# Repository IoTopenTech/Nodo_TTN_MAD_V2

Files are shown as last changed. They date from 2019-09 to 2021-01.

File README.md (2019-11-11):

# Nodo_TTN_MAD_V2_2
Documentación, hardware y software del nodo TTN MAD V2.2 desarrollado por la comunidad The Things Network Madrid
En el wiki de este repositorio encontrarás más información sobre cómo montar/adquirir este nodo.
Si lo deseas, también puedes adquirirlo como un kit para montar o ya montado directamente en España (con factura) a través de Molukas:
https://shop.molukas.com/es/inicio/19-56-nodo-ttn-mad-v22.html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

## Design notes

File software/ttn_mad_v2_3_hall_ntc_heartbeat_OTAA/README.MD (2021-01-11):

Programa para el nodo V2.3 en el que la alimentación de la NTC se puede habilitar a demanda mediante el pin digital D6 (es el nodo V2.2 la NTC están constantemente alimentada).
Es el programa que se utiliza en TTNMAD_DOOR.

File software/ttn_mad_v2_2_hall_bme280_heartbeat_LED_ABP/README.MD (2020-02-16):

Ejemplo para la configuración con sensor de efecto Hall, BME280 (temperatura, presión y humedad), envío de heartbeat periódico, y activación/desactivación del LED mediante downlink.
El nodo se activa por ABP.
Envía la tensión de la batería, las lecturas del BME280, y el estado de la puerta cada vez que éste cambia, durmiendo entre cada envío por un máximo de 1 minuto, que es el tiempo predeterminado para el heartbeat.
Con cada heartbeat se envía la misma carga de pago (tensión de la batería, lecturas del BME280 y estado de la puerta).

Si tiene problemas para compilarlo por un error de tipo "segmentation fault", reduzca la versión de las placas Arduino a la versión 1.6.21.

Requiere las siguientes librerías:
* MCCI LoRaWAN LMIC Library by IBM, Matthis Kooijman, Terry Moore, ChaeHee Won, Frank Rose. Versión 2.3.2.
* Low-Power by Rocket Scream Electronics. Versión 1.6.0.
* CayenneLPP by Electronics Cats. Versión 1.0.1
* Adafruit Unified Sensor by Adafruit. Version 1.0.3.
* Adafuir BME280 Library by Adafruit. Version 1.0.8.
   * En el archivo Adafruit_BME280.h hay que cambiar la siguiente línea
   ```
   #define BME280_ADDRESS                (0x76)
   ```
   
Para reducir los requisitos de memoria FLASH de la librería MCCI se debe modificar su archivo MCCI_LoRaWAN_LMIC_library\project_config\lmic_project_config.h del siguiente modo:
```
// project-specific definitions
#define CFG_eu868 1
//#define CFG_us915 1
//#define CFG_au921 1
//#define CFG_as923 1
// #define LMIC_COUNTRY_CODE LMIC_COUNTRY_CODE_JP	/* for as923-JP */
//#define CFG_in866 1
#define CFG_sx1276_radio 1
//#define LMIC_USE_INTERRUPTS
#define DISABLE_PING
#define DISABLE_BEACONS
```

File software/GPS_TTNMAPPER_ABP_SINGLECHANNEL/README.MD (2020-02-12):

En este ejemplo utilizamos un GPS para enviar información a ttnmapper.

Este ejemplo está dirigido a usuarios que sólo disponen de un gateway Single Channel.

El nodo envía la información siempre por el canal 868.1 y en SF7.

Adicionalmente puede conectarse el pin de entrada de la batería al pin A1 mediante una resistencia de 1M para poder medir la tensión, y pulsando el botón (conectado al pin 8) se fuerza el envío de un paquete.

Se ha probado con un GPS VK2828U7G5LF y un GN-701.

Si utiliza el model GN-701 tendrá que retirar una resistencia para habilitar el pin EN (más información en el Wiki).

Cuando se usa el transmisor LoRa se deshabilita el GPS porque el conversor de tensión no es capaz de suministrar corriente suficiente para ambos.

El GPS está conectado al puerto Serial, por lo que el archivo GPSport.h de la librería NeoGPS debe modificarse para que su contenido sea el siguiente:
```
#ifndef GPSport_h
#define GPSport_h

#define gpsPort Serial
#define GPS_PORT_NAME "Serial"
#define DEBUG_PORT Serial

#endif
```
Además, en la librería NeoGPS, debe habilitarse la extracción del valor hdop (horizontal dilution of precision) descomentando la siguiente línea del archivo GPSfix_cfg.h:
```
#define GPS_FIX_HDOP
```
Por último, en la consola de The Thnings Network, debe utilizarse el siguiente decoder en la sección Payload formats:
```
function Decoder(bytes, port) {
    var decoded = {};
    //JavaScript Numbers are Always 64-bit Floating Point
    decoded.latitude = ((((bytes[0]<<(24+32))>>>0) + ((bytes[1]<<(16+32))>>>0) + ((bytes[2]<<(8+32))>>>0) + ((bytes[3]<<(32))>>>0))>>32)/10000000;
    decoded.longitude = ((((bytes[4]<<(24+32))>>>0) + ((bytes[5]<<(16+32))>>>0) + ((bytes[6]<<(8+32))>>>0) + ((bytes[7]<<(32))>>>0))>>32)/10000000;
    decoded.altitude = (((bytes[8]<<24)>>>0) + ((bytes[9]<<16)>>>0) + ((bytes[10]<<8)>>>0) + bytes[11]);
    decoded.hdop=(((bytes[12]<<8)>>>0) + bytes[13])/1000;
    decoded.bateria=(((bytes[14]<<8)>>>0) + bytes[15])*3.3/1023.0;
    return decoded;
}
```

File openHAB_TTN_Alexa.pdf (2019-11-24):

# Domótica openHAB + The Things Network + Alexa

Juan Félix Mateos Barrado
jfmateos@educa.madrid.org
juanfelixmateos@gmail.com

Medialab Prado
Noviembre 2019

## Objetivo

Juan Félix Mateos | 2

# Integrar un nodo de The Things Network en openHAB para poder conocer su temperatura y controlar su LED utilizando comandos de voz a

través de Alexa.

## openHAB

## •Open Home Automation BUS •Creado por Kai Kreuzer (2010) en Java

- Sofware abierto de domótica patrocinado por KNX,

## Z-Wave… - Funciona en Windows, Linux, MacOS, Raspberry

Pi…

## •A partir de openHAB se creó Eclipse SmartHome

(2013) para aplicaciones comerciales.

## Conceptos básicos

Juan Félix Mateos

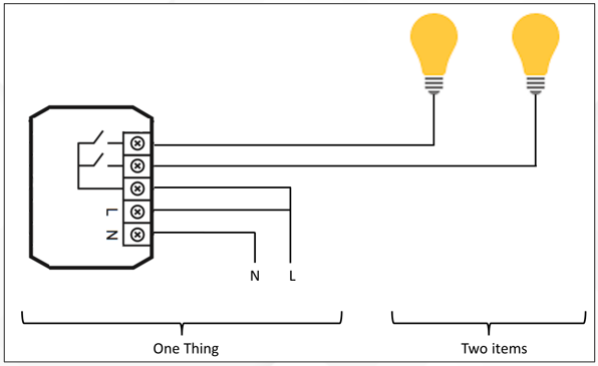
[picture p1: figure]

4

- Things, Items y Channels • Un sensor de temperatura, presión y

humedad es una thing (cosa física), que ofrece 3 canales (temperatura, presión y humedad), con los que el usuario podrá interactuar a través de un item (elemento virtual)
- Bindings • Son las extensiones de openHAB que nos

permiten usar distintos tipos de things (Z

Wave, Zigbee…)
- Rules • Sitemaps • Dashboards

## Orden del día

- Crear una aplicación y un dispositivo en The Things Network
- Instalar Java
- Instalar openHAB
- Instalar el binding JSONPath
- Crear una thing de tipo Generic MQTT Thing con 2 canales vinculados a 2 items:
- Temperatura
- LED
- Crear una regla que active/desactive el LED en el umbral de temperatura de 25º
- Crear un sitemap que muestre la fecha/hora, y los controles de Temperatura y el LED.
- Instalar el binding openHAB Cloud Connector
- Instalar la app de openHAB para el móvil.
- Instalar el binding Rest documentation
- Añadir metadatos a los items para poder controlarlos con Alexa.
- Instalar Alexa en el móvil.
- Configurar el skill de openHAB

## Crear aplicación y dispositivo en TTN

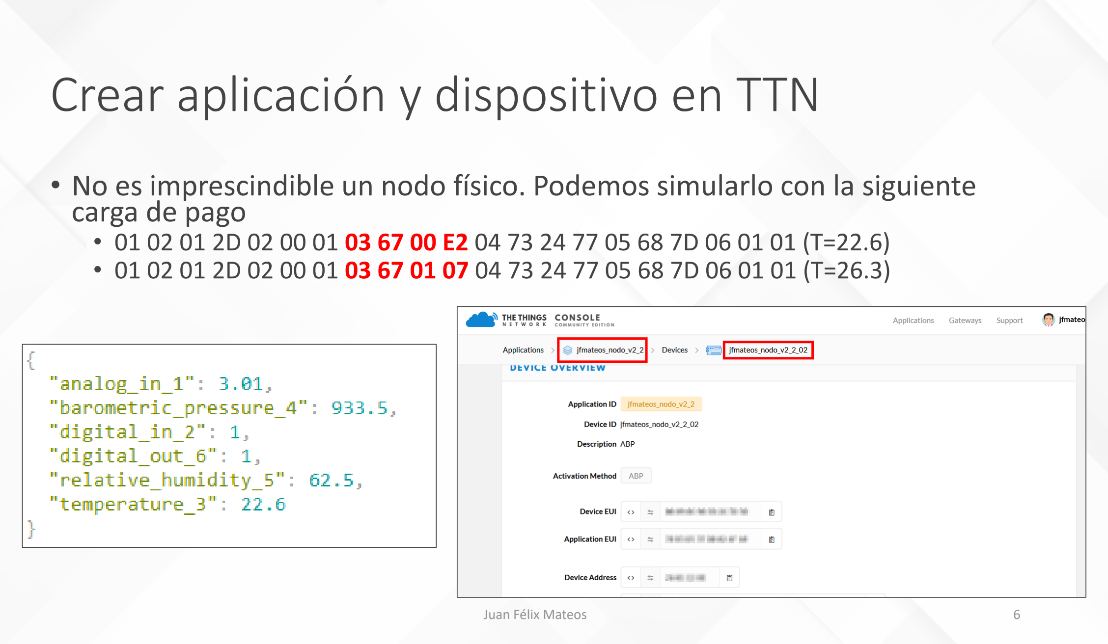
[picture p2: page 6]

- No es imprescindible un nodo físico. Podemos simularlo con la siguiente carga de pago
- 01 02 01 2D 02 00 01 03 67 00 E2 04 73 24 77 05 68 7D 06 01 01 (T=22.6)
- 01 02 01 2D 02 00 01 03 67 01 07 04 73 24 77 05 68 7D 06 01 01 (T=26.3)

## Instalación en Windows 1/2

## •Requiere Java 8 (se recomienda la versión Zulu) •Asegurarse de que está definida la variable de entorno JAVA_HOME

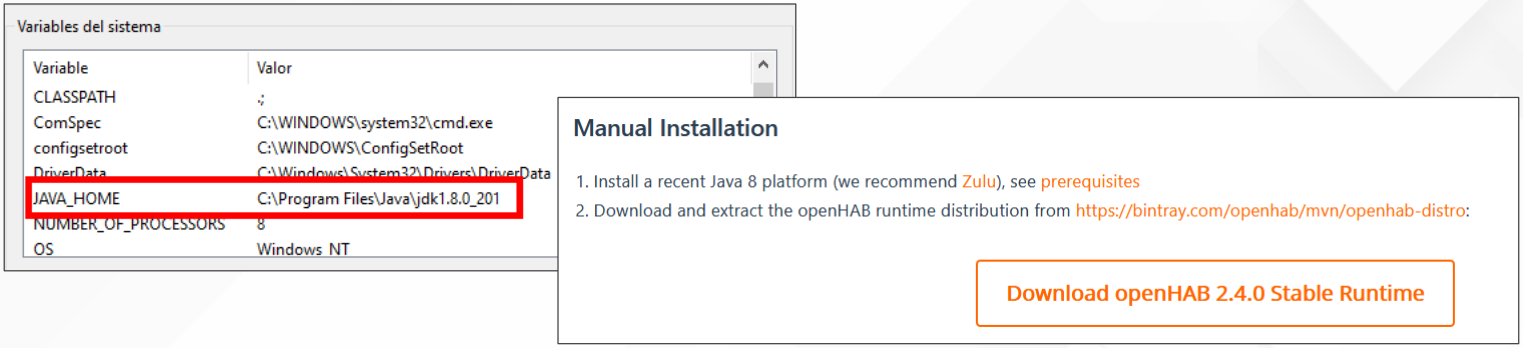
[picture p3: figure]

## Instalación en Windows 2/2

## •Descargar el archivo comprimido de openHAB •Descomprimirlo en una carpeta de nuestro disco duro; por ejemplo C:/openHAB •Ejecutar el archivo start.bat para iniciar openHAB •Acceder con el navegador web a localhost:8080

## Iniciar y detener openHAB

- A través de la consola:
- Windows: C:\openHAB\runtime\bin\karaf.bat
- logout
- Raspberry pi: Putty/SSH
- Usuario: openHABian
- Contraseña: openHABian
- sudo shutdown –h now

## Logs

- Hay 2 logs importantes:
- events.log → Todo los relacionado con las things
- openHAB.log → Todo lo relacionado con los bindings
- Windows
- C:\openHAB\userdata\logs
- Raspberry pi
- http://openHAB:9001/

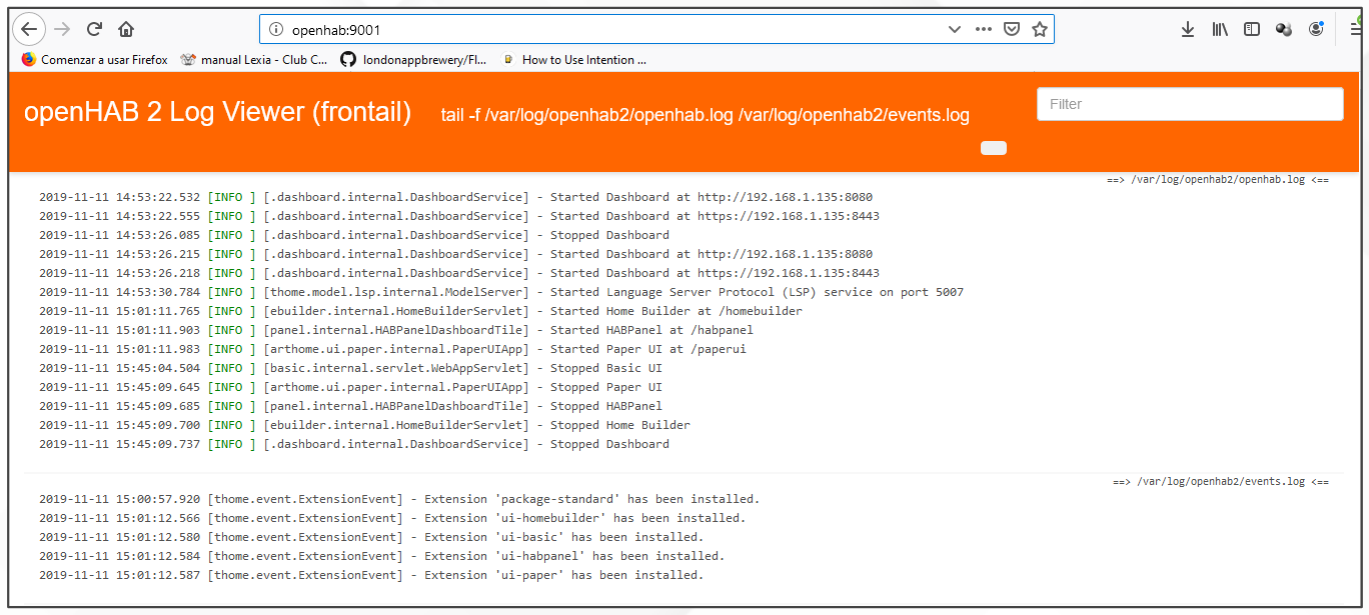
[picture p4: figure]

## Configuración inicial

## Se recomienda utilizar

la opción Standard,

## que instalará las interfaces: • Paper UI • Basic UI •Hab PANEL •Home Builder

## Interfaces (1/2)

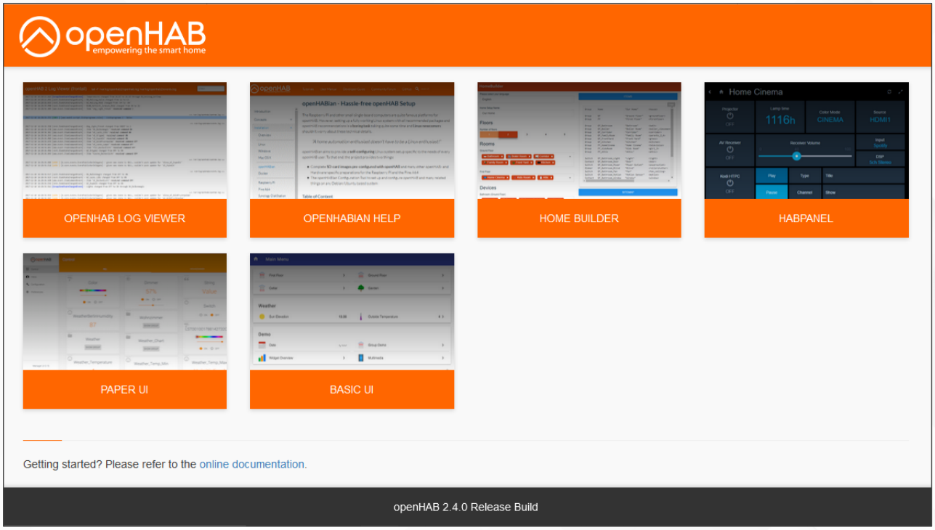
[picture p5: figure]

## Interfaces (2/2)

- Paper UI: Ideal para configurar openHAB.
- Basic UI: Ideal para mostrar los Site maps
- HABPanel: Sirve para diseñar Dashboards.
- Home Builder: Sirve para generar una configuración inicial compuesta por:
- Items
- Sitemaps
- Dashboards

## MQTT

- Broker
- Suscripción/Publicación
- Topic
- Vamos a vincular openHAB con el bróker MQTT de The Things Network

## MQTT

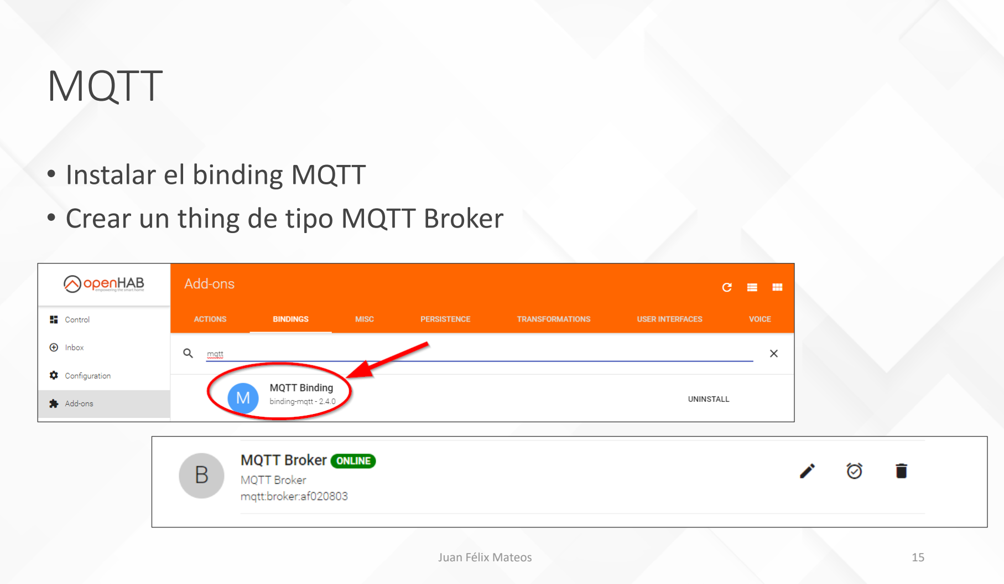
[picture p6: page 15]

- Instalar el binding MQTT
- Crear un thing de tipo MQTT Broker

## MQTT: Configurar la thing MQTT Broker

- Broker: eu.thethings.network
- Username: Nombre de la aplicación en TTN
- Password: Default key de TTN

## MQTT: Crear una Generic MQTT Thing

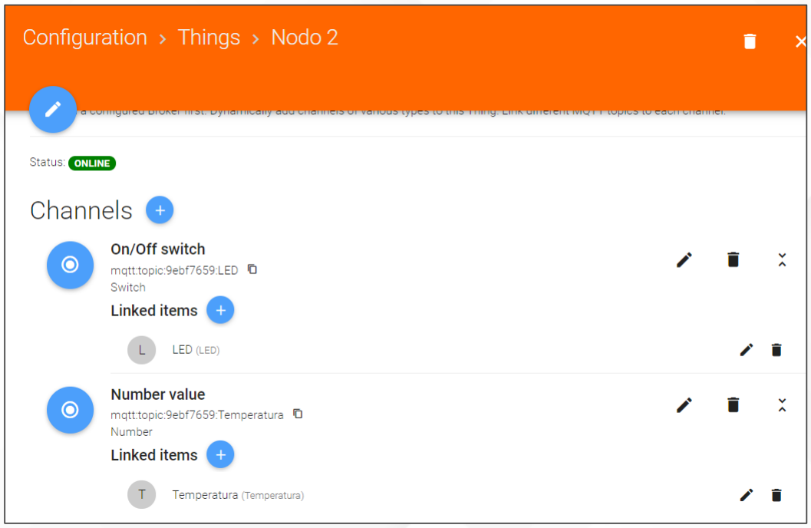
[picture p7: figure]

- El thing Broker es el soporte general
para poder usar MQTT en openHAB,
pero adicionalmente tenemos que crear un thing de tipo Generic MQTT Thing para cada elemento que queramos controlar.
- Crear una thing de tipo Generic MQTT Thing con 2 canales vinculados a los siguientes items:
- Number value: Temperatura
- On/Off Switch: LED

## MQTT: Canal para recibir uplink

- Configurar el canal de tipo Number Value del siguiente modo

El 20 de noviembre de 2019 han desactivado la publicación de los decoded fields en topics MQTT independientes;
consecuentemente este sistema no funciona (ver diapositiva siguiente)

## MQTT: Canal para recibir uplink (alternativa)

- En lugar de suscribirnos al topic concreto de la temperatura, nos suscribiremos al topic completo, y extraeremos de él la temperatura mediante una transformación.
- Instalar el binding JSONPath Transformation

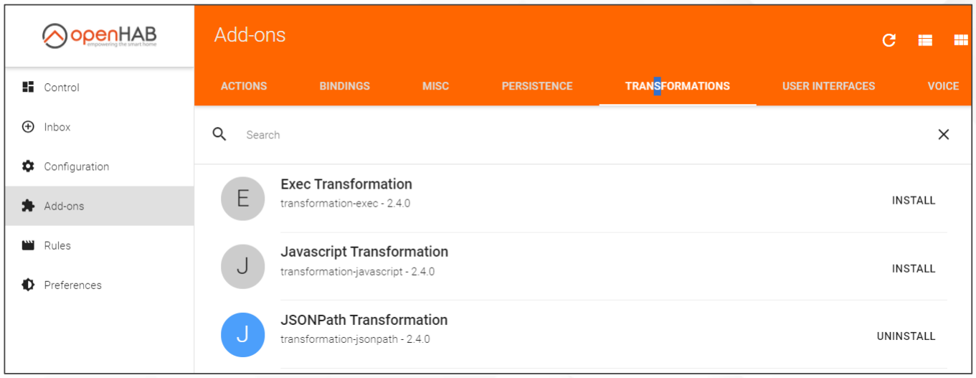
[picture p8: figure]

## MQTT: Canal para recibir uplink (alternativa)

- Configurar el canal de temperatura del siguiente modo

## MQTT: Canal para enviar downlink

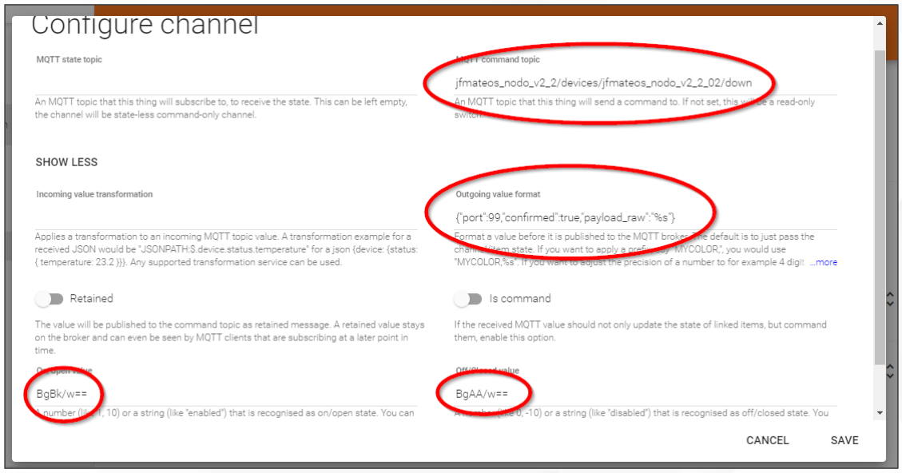
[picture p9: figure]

- Configurar el canal de tipo
On/Off Switch del siguiente
modo
- BgBk/w== y BgAA/w== son la codificación en BASE64 de 06 00 64 FF y 06 00 00 FF, que son la carga de pago que
espera recibir el nodo para encender y apagar el led,
respectivamente
- jfmateos_nodo_v2_2/devices/jf mateos_nodo_v2_2_02/down
- {"port":99,"confirmed":true,"pa yload_raw":"%s"}

## MQTT: Canal para enviar downlink

- En la versión 2.4 de openHAB hay un bug que impide que se inicie automáticamente el cliente MQTT
- Para resolverlo hay que cerrar openHAB (logout) y volver a iniciarlo.

## Reglas

## Nos permiten reaccionar ante:

- el cambio de estado de los ítems
- Things y canales (de forma más limitada)
- instantes (fecha y/u hora) concretos
- eventos del sistema (que se inicie o se apague)

## con acciones como:

- enviar un comando a un item
- utilizar un servicio (enviar un mail, notificación…)

## - La sintaxis está basada en Xbase

## Reglas: Encender/apagar el LED en el umbral de 25º

Crear en la carpeta C:\openHAB\conf\rules un archivo llamado default.rules con el siguiente contenido:

rule "LED"
when
Item Temperatura changed
then
if (Temperatura.state >= 25 && previousState<25) { LED.sendCommand(ON)
} else {
if(Temperatura.state < 25 && previousState>=25) { LED.sendCommand(OFF)
}
}
end

## Sitemaps

Son representaciones destinadas al usuario para conocer el estado del sistema o interactuar con él.
Están compuestos por elementos de distintos tipos:
- Pulsadores
- Deslizadores
- Selectores de color
- …
Los sitemaps se crean en archivos de texto con la extensión sitemap dentro de la carpeta:
- C:\openHAB\conf\sitemaps
En Paper UI disponemos de la sección Control, pero sólo sirve para Things (los sitemaps y dashboards funcionan principalmente a nivel de items).

## Sitemaps

Cada sitemap debe empezar con un elemento de tipo sitemap sitemap <nombre> label="<título de la pantalla inicial>" {
[resto de elementos]
}
El <nombre> debe coincidir con el nombre del archivo; por ejemplo, si el sitemap se llama habitacion_invitados, el archivo deberá llamarse habitacion_invitados.sitemap.

## Sitemaps

Cada elemento tendrá la siguiente sintaxis: tipo item=nombre label="Rotulo"
Donde tipo puede ser:
- Switch
- Slider
- Text
- Image
- Frame (para agrupar)
- …
Y nombre es el nombre del item.

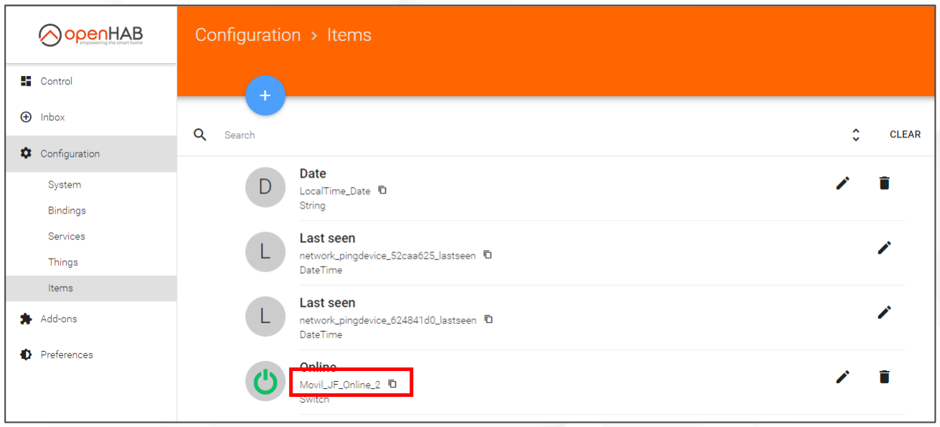
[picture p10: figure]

## Sitemaps

Si lo deseamos podemos
cambiar el icono del item en el sitemap eligiendo cualquiera de los disponibles en:
https://www.openHAB.org/docs/configuration/iconsets/classic/ Y escribiendo su nombre en Category

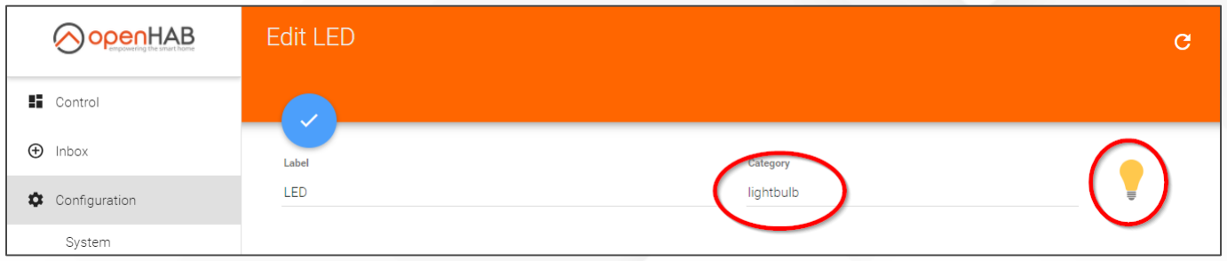
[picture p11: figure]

## Sitemaps: things

Crear el archivo C:\openHAB\conf\sitemaps\ttn.sitemap con el siguiente contenido:

sitemap ttn label="<The Things Network Madrid>" {
Switch item=LED label="LED"
Text item=Temperatura label="Salon [%.1f °C]" icon="temperature" }

## Sitemaps: Basic UI

Configura Basic UI para que utilice como sitemap por defecto el que hemos creado anteriormente (habitación_invitados).

## Sitemaps: Basic UI

Acceder a Basic UI a través de http://localhost:8080

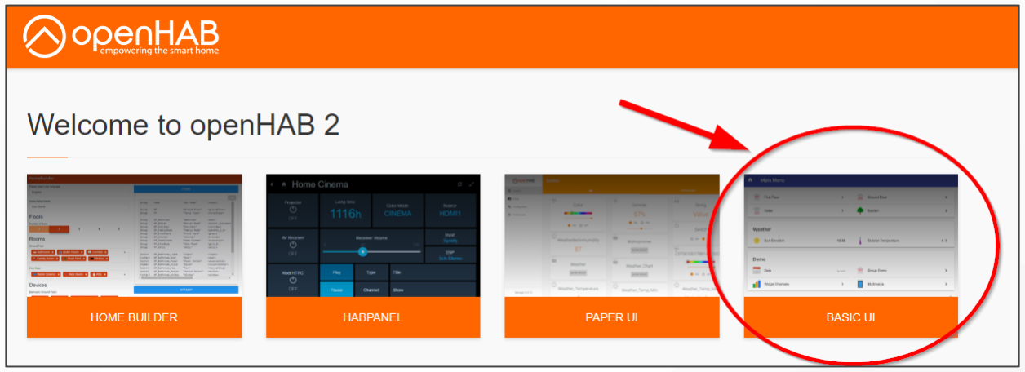
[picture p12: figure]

## Sitemaps

Además de crear ítems a través de Paper UI, también podemos hacerlo a través de documentos de texto con la extensión .items en la carpeta C:\openHAB\conf\items
Por ejemplo, vamos a incluir en el sitemap un item que muestre la fecha:
1. Importar el binding NTP.
2. Crear la thing correspondiente a través de Inbox.
3. Configurar el item a través de un archivo .items.

## Sitemaps

Importar el binding NTP.

## Sitemaps

Crear la thing correspondiente a través de Inbox.

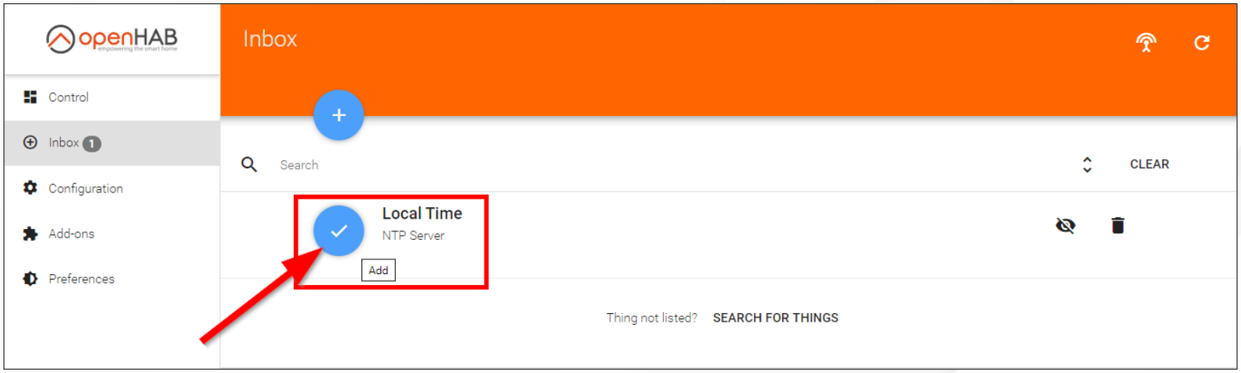
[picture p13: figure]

## Sitemaps

Cada elemento (item)
debe crearse con la
siguiente sintaxis
tipoElemento
nombreElemento
"Descripción" <icono> {
canal }
Donde tipoElemento
puede ser cualquiera de la tabla.

## Sitemaps

<icono> puede ser cualquiera de esta lista https://www.openHAB.org/docs/configuration/iconsets/classic/

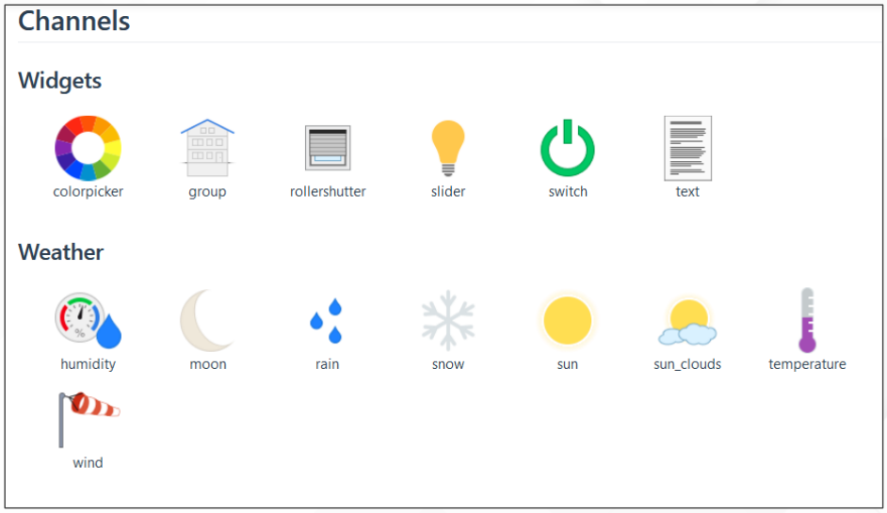
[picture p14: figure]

## Sitemaps

Y canal es el nombre del canal que vincula la thing con el item, y que podemos obtener en la configuración de la thing

## Sitemaps

Crear el archivo C:\openHAB\conf\items\miselementos.items con el siguiente contenido:

String Fecha_NTP "Fecha" <calendar> { channel="ntp:ntp:local:string" }

Y modificar el archivo ttn.sitemap:

sitemap ttn label="<The Things Network Madrid>" {
Text item=Fecha_NTP label="Fecha"
Switch item=LED label="LED"
Text item=Temperatura label="Salon [%.1f °C]" icon="temperature" }

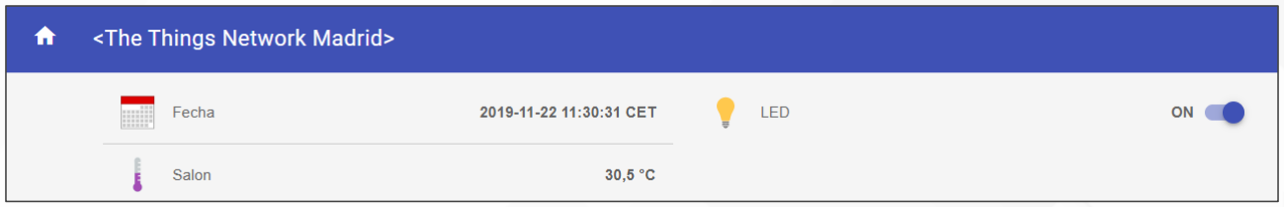
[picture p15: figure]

## App móvil

Instalar el Add-on openHAB Cloud Connector

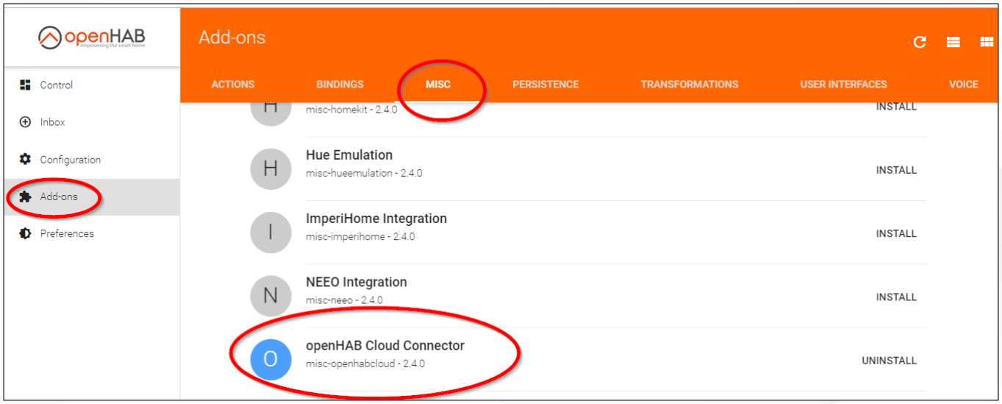
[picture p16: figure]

## App móvil

Configurar openHAB Cloud Connector para que utilice el servidor https://myopenhab.org

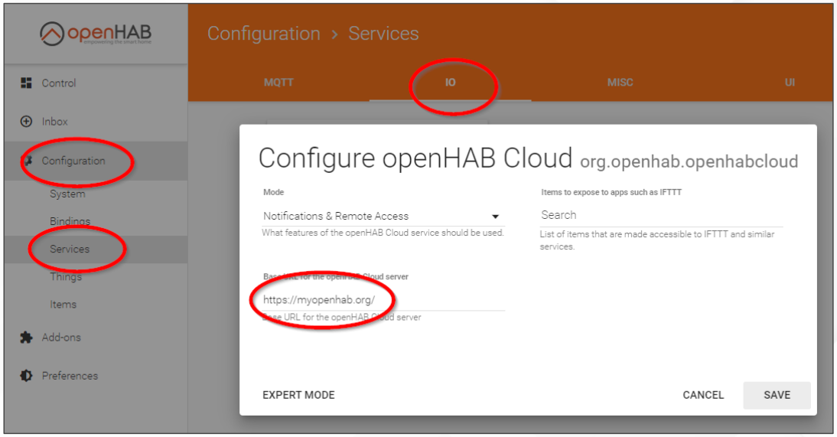
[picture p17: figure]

## App móvil

Crear una cuenta en
https://myopenhab.org
- UUID:
C:\openHAB\userdata\uuid
- Secret:
C:\openHAB\userdata\ope
nhabcloud\secret

## App móvil

Instalar la aplicación en el móvil

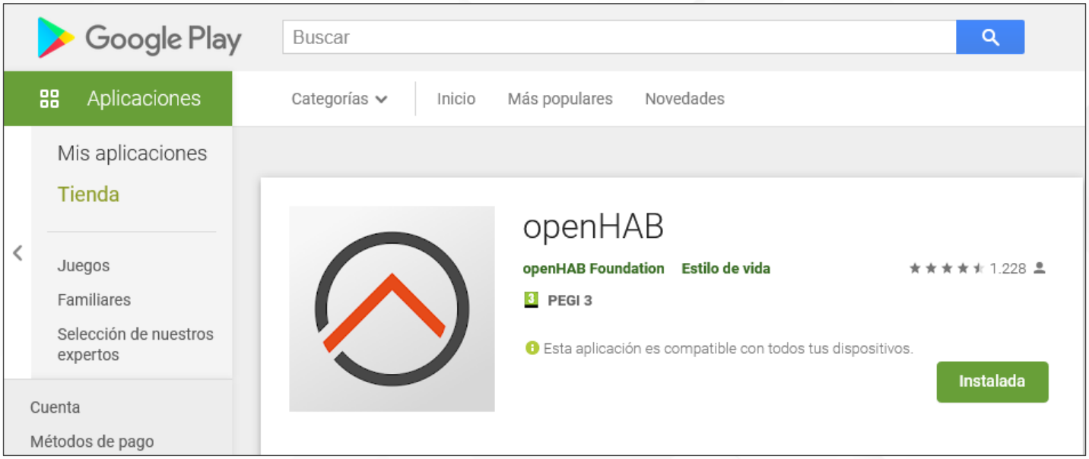
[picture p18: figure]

## App móvil

Configurar la app para que se conecte a myopenhab.org

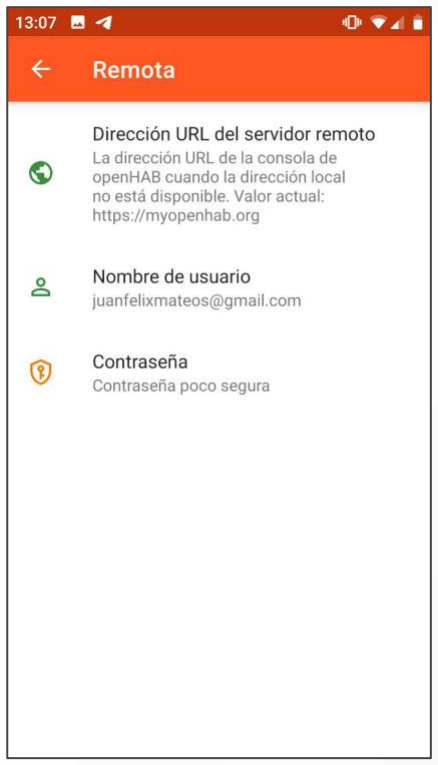
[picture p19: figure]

## Alexa

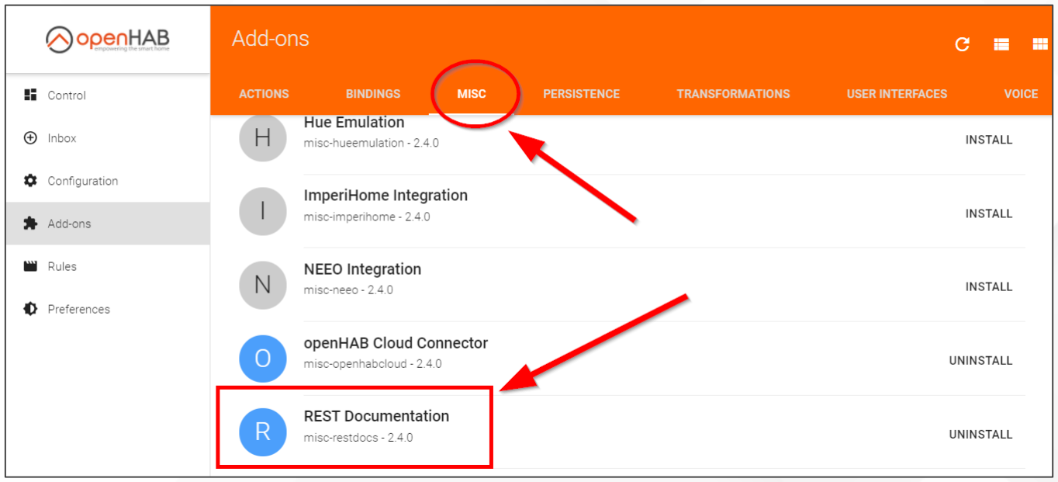
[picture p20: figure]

Para que Alexa pueda identificar a nuestro nodo necesitamos
aportar a los items
metainformación que indique qué posibilidades ofrecen.
Para aportar esta
metainformación vamos a recurrir a la Rest API de openHab que, si instalamos el binding openHAB Rest Documentation, está
disponible a través de Swagger en: • http://localhost:8080/doc/index

.html (http://localhost:8080/doc/index.html)

## Alexa

El listado de metadatos está disponible en:
- https://www.openhab.org/docs/ecosystem/alexa/#supported-item-metadata
- Por ejemplo:
- Interruptor: PowerController.powerState
- Sensor: TemperatureSensor.temperature

## Alexa

Metadatos de LED

## Alexa

Podemos comprobar que el metadato se ha añadido correctamente revisando el archivo:
- C:\openHAB\userdata\jsondb\org.eclipse.smarthome.core.items.Me tadata.json

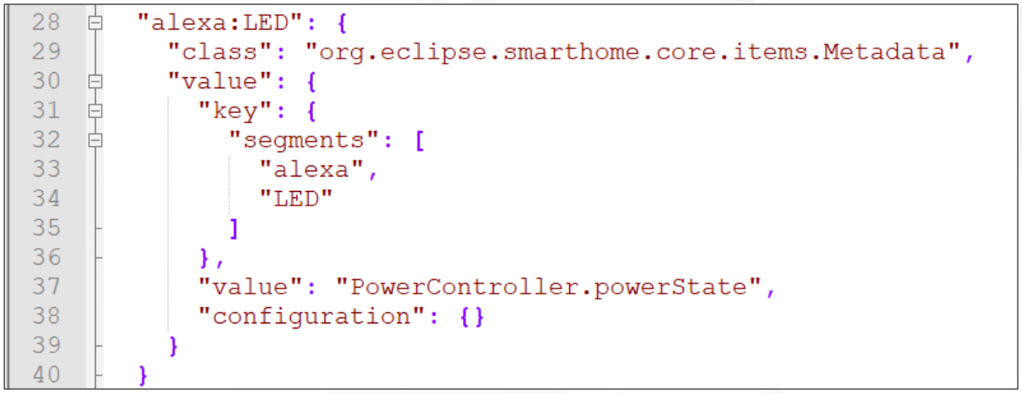
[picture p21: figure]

## Alexa

Metadatos de Temperatura

## Alexa

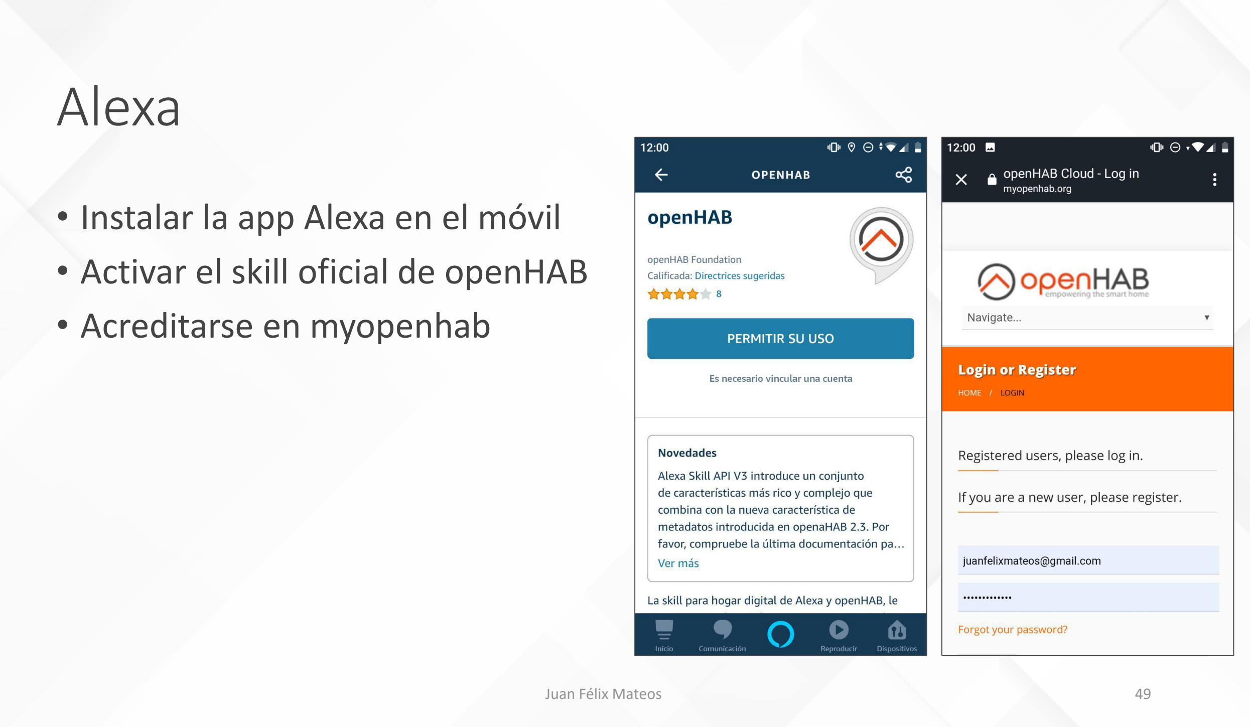
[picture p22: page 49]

- Instalar la app Alexa en el móvil
- Activar el skill oficial de openHAB
- Acreditarse en myopenhab

## Alexa

- Aceptar la autorización OAuth2
- Permitir que Alexa detecte nuestros 2 dispositivos

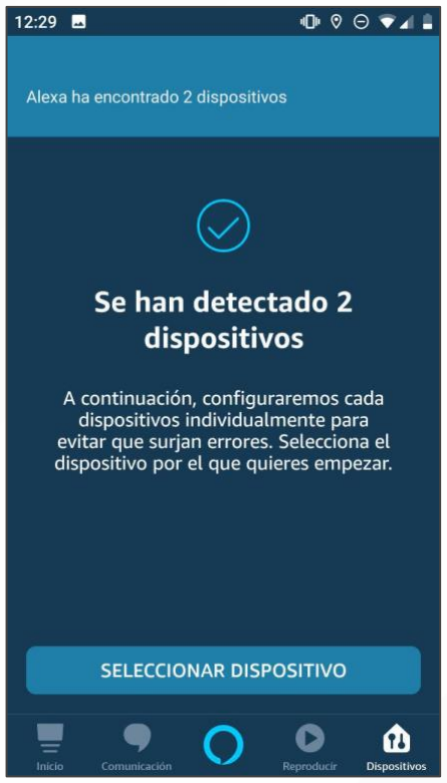
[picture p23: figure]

## Alexa

Interactuar con los siguientes comandos de voz:
- ¿Cuál es la temperatura de Temperatura?
- Activa LED
- Desactiva LED
- ¿Cuál es el estado de LED?
- Todavía no está disponible ¿o sí?
- https://github.com/openhab/openhab-alexa/issues/239

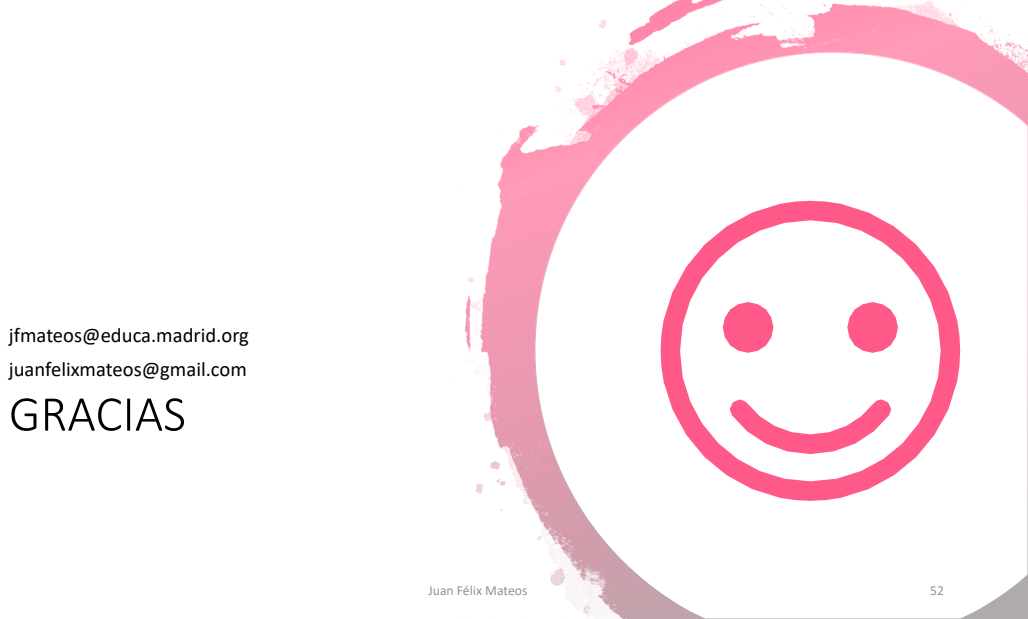
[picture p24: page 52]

jfmateos@educa.madrid.org
juanfelixmateos@gmail.com
GRACIAS

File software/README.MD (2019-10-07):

En esta carpeta se recogen varios ejemplos de funcionamiento del nodo TTN MAD V2.2.

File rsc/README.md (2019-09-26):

Esta carpeta contiene las imágenes y recursos que se utilizan en el wiki.

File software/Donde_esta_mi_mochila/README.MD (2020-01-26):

Este ejemplo puede funcionar en dos modos diferentes:
* Modo Heartbeat: Envía cada 15' la tensión de la batería 
* Modo Tracking: Envía cada 5' la tensión de la batería, la posición GPS y la MAC de los 2 puntos de acceso con mejor RSSI. La adquisición de las direcciones MAC permitiría obtener una geolocalización aproximada, incluso en interiores o zonas sin cobertura GPS, mediante el uso de servicios como http://api.mylnikov.org/geolocation/wifi?v=1.1&data=open&bssid={wifi-bssid}

Identificación de elementos

Nodo completo

La carga de pago usa el estándar Cayenne LPP. Como no existe un modelo de datos para direcciones MAC en LPP, se codifican los 6 bytes de cada MAC en 3 paquetes de 2 bytes, que se envían cada uno como datos de luminosidad.

Integración con MyDevices

Inicialmente arranca en el modo Heartbeat, y se puede intercambiar entre uno y otro modo usando cualquiera de estos dos métodos:
* Usando el botón: Con una triple pulsación del botón en menos de 2'' pero con más de 500ms de separación entre pulsación y pulsación. El botón está conectado a los bornes SW y GND del terminal de tornillos verde. El botón elegido es el mismo que para la extensión WiFi (SMD 3x6x2,5).
* Mediante downlink: Se recomienda usar downlink con ACK para asegurarse de que es efectivamente recibido por el nodo. Un downlink con la carga de pago 02 00 64 FF activará el modo Tracking, y usando la carga de pago 02 00 00 FF se activará el modo Heartbeat.

En modo Tracking el LED del nodo parpadea al menos cada 8 segundos en la fase dormida, y cada segundo aproximadamente si está en las fases de adquisición de GPS o WiFi.

Requiere las extensiones WIFI, BOOSTER y GPS, y adicionalmente un botón SMD 3x6x2,5 como el de la extensión WIFI..

Puede configurarse a través del portal cautivo WiFi para unirse a la red por OTAA o ABP.
Sin embargo, en modo ABP no almacena de forma no volátil los contadores, por lo que ante un fallo de alimentación se reiniciarían; en caso de configurarlo en modo ABP se recomienda deshabilitar la comprobación de contador en la consola de The Things Network.

Requiere las siguientes librerías:
* MCCI LoRaWAN LMIC Library by IBM, Matthis Kooijman, Terry Moore, ChaeHee Won, Frank Rose. Versión 2.3.2.
* Low-Power by Rocket Scream Electronics. Versión 1.6.0.
* NeoGPS by SlashDevin 4.2.9

Para reducir los requisitos de memoria FLASH de la librería MCCI se debe modificar su archivo MCCI_LoRaWAN_LMIC_library\project_config\lmic_project_config.h del siguiente modo:
```
// project-specific definitions
#define CFG_eu868 1
//#define CFG_us915 1
//#define CFG_au921 1
//#define CFG_as923 1
// #define LMIC_COUNTRY_CODE LMIC_COUNTRY_CODE_JP	/* for as923-JP */
//#define CFG_in866 1
#define CFG_sx1276_radio 1
//#define LMIC_USE_INTERRUPTS
#define DISABLE_PING
#define DISABLE_BEACONS
```
Se ha probado con un GPS G28U7FTTL.
Cuando se usa el transmisor LoRa se deshabilita el GPS porque el conversor de tensión no es capaz de suministrar corriente suficiente para ambos. Tampoco se utilizan simultáneamente el GPS y el ESP03 por el mismo motivo.
El GPS está conectado al puerto Serial, por lo que el archivo GPSport.h de la librería NeoGPS debe modificarse para que su contenido sea el siguiente:
```
#ifndef GPSport_h
#define GPSport_h

#define gpsPort Serial
#define GPS_PORT_NAME "Serial"
#define DEBUG_PORT Serial

#endif
```
La tensión de la batería se mide a través del pin A1 intercalando una resistencia de 1M entre el borne 3v3 del terminal de tornillos y el orificio A1 de la sub-placa de expansión.

Se ha incluido también una resistencia de 1M en configuración puldown entre el pin PIR de la sub-placa de expansión y el ping GND de la sub-placa de expansión para que el GPS arranque inicialmente deshabilitado.

Para entrar en el modo de configuración por WiFi hay que mantener pulsado el botón del pcb (no el de cambio entre los modos Heartbeat y Tracking) durante el arranque del nodo.

Cuando el ESP03 arranca empieza a mandar por el puerto serie "IoT" cada segundo, y espera recibir un "1" para entrar en el modo de configuración por WiFi, o un "2" para entrar en el modo de adquisición de las direcciones MAC de los 2 puntos de acceso con mejor RSSI.

El modelo 3D de la caja está diseñado con TinkerCAD y disponible en  https://www.tinkercad.com/things/hX5CWUOLzT4 

El asa se sujeta mediante 2 tuercas M2 y dos tornillos M2x5mm.
El soporte para el botón conviene fijarlo con pegamento termofusible.

Piezas 3D

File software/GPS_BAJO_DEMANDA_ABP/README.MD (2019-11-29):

En este ejemplo utilizamos un GPS.
El nodo envía un heartbeat cada 24 segundos con la tensión de la batería.
Cada 12 ciclos de 24 segundos, incluye en el heartbeat la posición GPS (si consigue hacer un fix antes de 5 minutos).
El usuario puede enviar un downlink con la carga de pago 02 00 64 FF para activar el modo de seguimiento; en este modo el GPS se habilita y se envía un paquete cada minuto.
Enviando un downlink con la carga de pago 02 00 00 FF se desactiva el modo de seguimiento.
Se ha probado con un GPS VK2828U7G5LF.
Cuando se usa el transmisor LoRa se deshabilita el GPS porque el conversor de tensión no es capaz de suministrar corriente suficiente para ambos.
El GPS está conectado al puerto Serial, por lo que el archivo GPSport.h de la librería NeoGPS debe modificarse para que su contenido sea el siguiente:
```
#ifndef GPSport_h
#define GPSport_h

#define gpsPort Serial
#define GPS_PORT_NAME "Serial"
#define DEBUG_PORT Serial

#endif
```


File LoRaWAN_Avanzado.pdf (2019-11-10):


CONSTRUYENDO UNA RED GLOBAL DE INTERNET

DE LAS COSAS ENTRE TOD@S

Facendo IoT con LoRaWAN. Introdución

juanfelixmateos@gmail.com

Integraciones

## - Data Storage

## - Cayenne

## - IFTTT

## - Node-RED

Juan Félix Mateos

Data Storage



Data Storage

Data Storage


Cayenne MyDevices


Cayenne MyDevices


Cayenne MyDevices


Cayenne MyDevices


Cayenne MyDevices


IFT T T = If This Then That


IFT T T = If This Then That


IFT T T = If This Then That

IFT T T = If This Then That


IFT T T = If This Then That

IFT T T = If This Then That

IFT T T = If This Then That


IFT T T = If This Then That


IFT T T = If This Then That


IFT T T = If This Then That

Node-RED

- Desarrollado por IBM en 2013 → Open Source
- Objetivo: Facilitar la construcción de sistemas IoT
- Programación visual basada en nodos y flujos
- Los nodos "consumen" y "produce" mensajes
- Un mensaje es un objeto JavaScript, que contiene al menos la propiedad payload
- msg={payload:"juanfe"};
- Adicionalmente, por defecto, todos los mensajes poseen las propiedades topic y _msgid

Node-RED: Tipos de nodos

- Entrada
- Salida
- Función
- Otros

Node-RED: Nodos y deployment


- Deployment/Despliegue = Poner en funcionamiento


Node-RED: Ejemplo básico

- En función del valor recibido, redirigimos la ejecución hacia un nodo u otro


Node-RED: Fred


Node-RED: Fred

Node-RED: Fred


Node-RED: Fred


Node-RED: Fred

HT TP Integration

- Podemos utilizar RequestBin para analizar el formato que utiliza TTN


YOU ARE THE NETWORK

LET ’S BUILD THIS THING TOGETHER!

Juan Félix Mateos

juanfelixmateos@gmail.com

w w w. t h e t hi n g s n e t w o r k . o r g

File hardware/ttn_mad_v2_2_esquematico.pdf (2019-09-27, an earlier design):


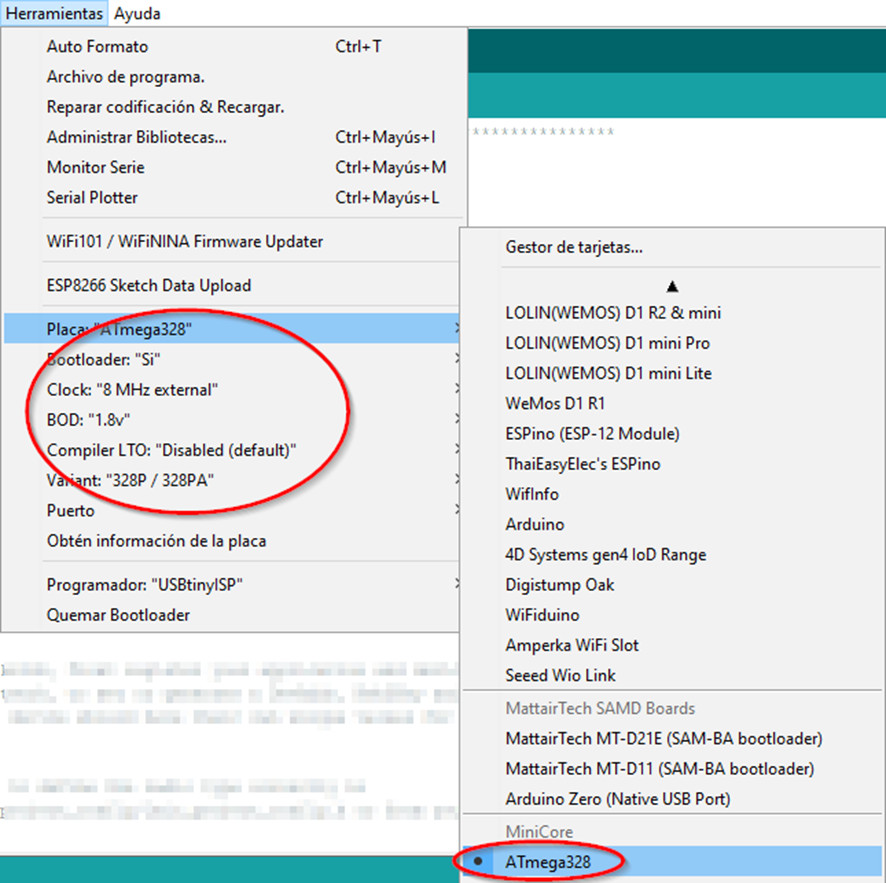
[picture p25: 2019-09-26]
rsc/TTN_MAD_V2_2_minicore.jpg

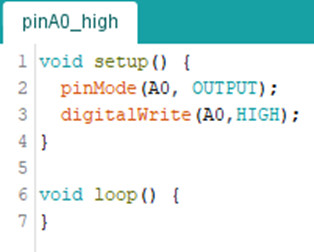
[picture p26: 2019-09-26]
rsc/TTN_MAD_V2_2_enableesp03.jpg

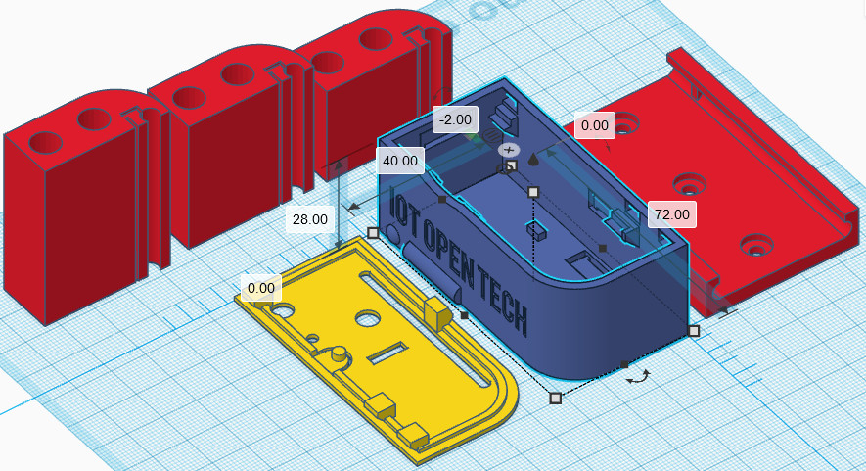
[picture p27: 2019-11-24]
rsc/TTN_MAD_V2_2_caja3d.jpg

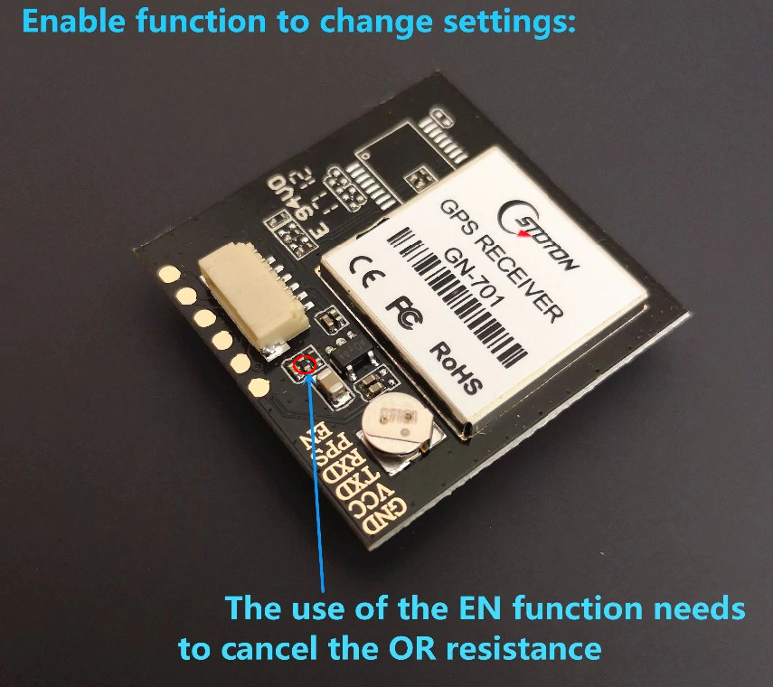
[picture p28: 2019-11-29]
rsc/gn-701.jpg

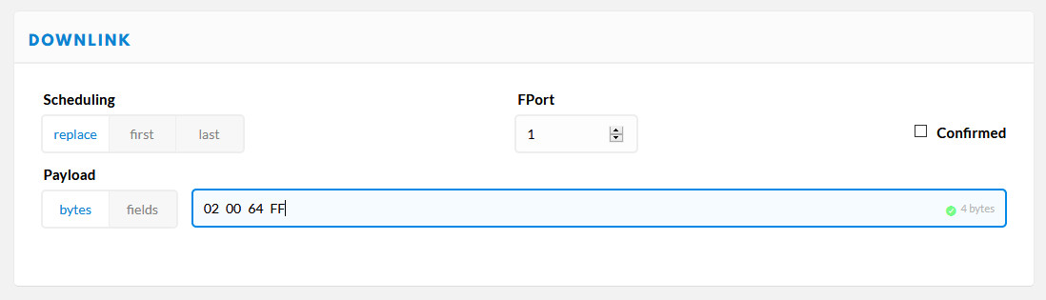
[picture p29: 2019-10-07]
rsc/TTN_MAD_V2_2_downlink.jpg

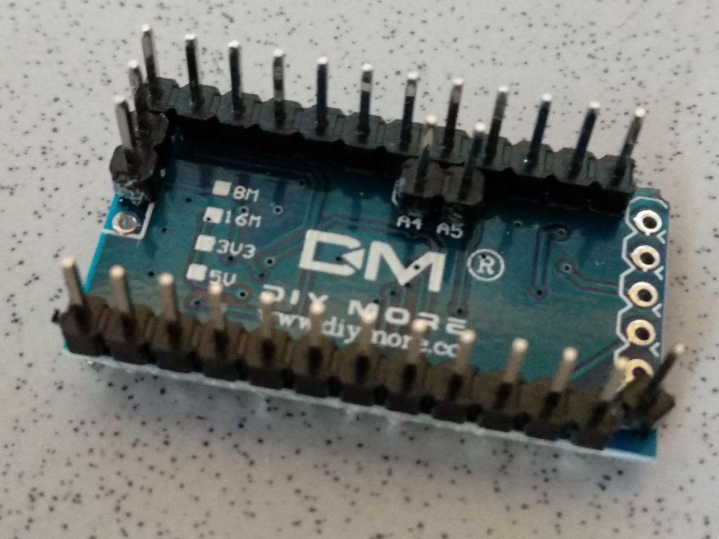
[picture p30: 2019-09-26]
rsc/ttn_mad_v2_arduino.jpg

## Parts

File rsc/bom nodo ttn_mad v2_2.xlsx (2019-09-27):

BOM nodo TTN MAD V2.2
Configuración | Componentes | Ejemplo de enlace de compra | Observaciones
Básica
 | 1x Arduino Pro Mini 8MHz 3.3V | https://es.aliexpress.com/item/32672156652.html
 | 1x RFM95W versión 868 MHz | https://es.aliexpress.com/item/32811523237.html
 | 1x Antena helicoidal | https://es.aliexpress.com/item/1989211654.html
 | 1x Header 4 entradas con tornillo | https://es.aliexpress.com/item/32620313513.html
 | 1x Portabaterías doble AAA | https://es.aliexpress.com/item/32970184341.html
 | 1x Botón On/Off | https://es.aliexpress.com/item/32696389272.html
 | 2x Batería alcalina AAA
Extensión Hall
 | 1x Sensor efecto hall (recomendado) o reed switch abierto en presencia del imán | https://www.mouser.es/ProductDetail/595-DRV5032FBDBZR | Recomendado
 |  | https://es.aliexpress.com/item/32762713233.html | Alternativa 1. Incluye el imán
 |  | https://es.aliexpress.com/item/32791579301.html | Alternativa 2.
 | 1x Imán de neodimio cilíndrico 5x10mm (sólo si no lo incluye el sensor anterior) | https://es.aliexpress.com/item/4000087186269.html
Extensión auxiliar I2C
 | 2x Resistencia 4.7K en formato 0603 | https://es.aliexpress.com/item/32506721498.html
Extensión auxiliar booster
Esta extensión es imprescindible para los componentes que requieren alimentación a 3.3V, como el ESP03. Además permite aprovechar mejor las baterías. | 1x TPS613221ADBVR | https://www.mouser.es/ProductDetail/595-TPS613221ADBVR
 | 1x Bobina 2.2uH | https://www.mouser.es/ProductDetail/652-SRN2512-2R2M
 | 2x Condensador 10uF en formato 0603 | https://es.aliexpress.com/item/32908565720.html
 | 2x Condensador 22uF en formato 0603 | https://es.aliexpress.com/item/32945148180.html
Extensión auxiliar puerto de ampliación
El puerto de ampliación puede utilizarse para conectar otros sensores y actuadores (ej. GPS), o bien para colocar un sensor a cierta distancia del nodo principal (ej. dentro de un congelador). | 1x Cable FPC 10p pines forward direction 0.5mm de pitch de la longitud deseada | https://es.aliexpress.com/item/32957238371.html
 | 2x Conector FPC 10 pines 0.5mm de pitch | https://es.aliexpress.com/item/32794865292.html
Extensión WiFI (recomendada). Requiere extensión auxiliar booster
Permite configurar el nodo a través de una página web sin tener que usar un programador conectado al ordenador. | 1x Esp03 | https://es.aliexpress.com/item/32834908262.html
 | 3x Resistencia 10k en formato 0603 | https://es.aliexpress.com/item/32887413843.html
 | 1x MIC94092YC6TR | https://www.mouser.es/ProductDetail/998-MIC94092YC6TR
 | 1x Condensador 100n en formato 0603 | https://es.aliexpress.com/item/32947901307.html
 | 1x Botón momentáneo normalmente abierto | https://es.aliexpress.com/item/32809371269.html
Extensión LED
 | 1x LED rojo en formato 1206 | https://es.aliexpress.com/item/32985163457.html
 | 1x Resistencia 150ohm en formato 0603 | https://es.aliexpress.com/item/4000094254339.html
Extensión buzzer
 | 1x Buzzer | https://es.aliexpress.com/item/32458823676.html
 | 1x BC817 | https://es.aliexpress.com/item/32947715617.html
 | 1x Resistencia 150ohm en formato 0603 | https://es.aliexpress.com/item/4000094254339.html
Extensión memoria ferromagnética. Requiere extensión auxiliar booster y extensión auxiliar I2C
Los paquete LoRaWAN incluyen un contador creciente por motivos de seguridad. Si el nodo se configura para acceder a la red por ABP y sufre una pérdida de alimentación, al reiniciarse deberá seguir con la secuencia de contador, por lo que necesitará tenerla almacenada en una memoria no volátil (que es lo que aporta esta extensión). Si configuramos el nodo para acceder a la red por OTAA, o si anulamos la medida de seguridad del contador no se requiere esta extensión. | 1x FM24CL16B | https://www.mouser.es/ProductDetail/877-FM24CL16B-GTR
 | 1x Condensador 100n en formato 0603 | https://es.aliexpress.com/item/32947901307.html
Extensión BME280. Requiere extensión auxiliar I2C
 | 1x BME280 | https://www.mouser.es/ProductDetail/Bosch-Sensortec/BME280
 | 1x Condensador 100n en formato 0603 | https://es.aliexpress.com/item/32947901307.html
Extensión BMA253. Requiere extensión auxiliar I2C
 | 1x BMA253 | https://www.mouser.es/ProductDetail/Bosch-Sensortec/BMA253
 | 1x Condensador 100n en formato 0603 | https://es.aliexpress.com/item/32947901307.html
Extensión PIR. Requiere extensión auxiliar booster
 | 1x MH-SR602 | https://es.aliexpress.com/item/32899134070.html
 | 1x Header hembra 3 pines | https://es.aliexpress.com/item/32849618420.html
Extensión GPS. Requiere extensión auxiliar booster y extensión auxiliar puerto de ampliación
 | 1x Módulo GPS | https://es.aliexpress.com/item/32947981053.html
Extensión LDR
 | 1x LDR tipo GL5506 | https://es.aliexpress.com/item/32630707917.html
 | 1x Resistencia 4.7k en formato 0603 | https://es.aliexpress.com/item/32506721498.html
Extensión NTC
 | 1x NTC MF52 10K 3950 | https://es.aliexpress.com/item/2044621392.html
 | 1x Resistencia 8.2k en formato 0603 | https://es.aliexpress.com/item/4000134157979.html

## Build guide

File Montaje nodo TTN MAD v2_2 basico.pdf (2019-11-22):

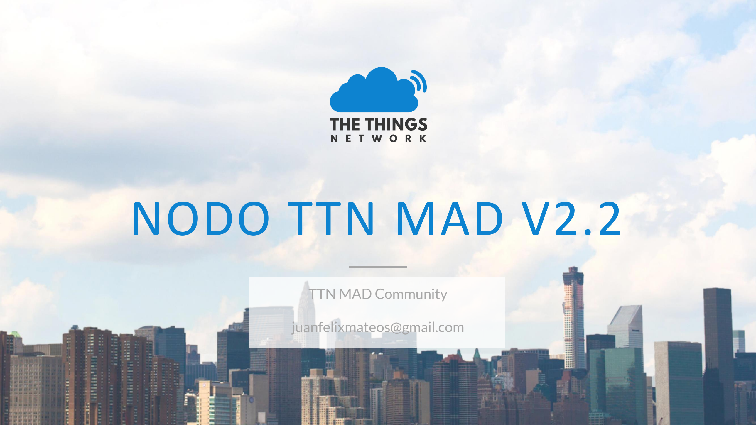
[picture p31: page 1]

# NODO TTN MAD V2.2

TTN MAD Community

juanfelixmateos@gmail.com

AGENDA

¿Qué es el nodo TTN MAD v2.2?

La consola de TTN

Programa en Arduino para el nodo TTN MAD v2.2

Configuraciones del nodo

Montaje y programación de la configuración básica

Integraciones

1

2

3

4

5

6

Es un nodo LoRaWAN diseñado con los siguientes requerimientos:

- Fácil de montar
- Económico (monetaria y energéticamente)
- Ampliable
- Muy flexible.

¿Qué es el nodo TTN MAD v2.2?

Nodo T TN MAD v2.2

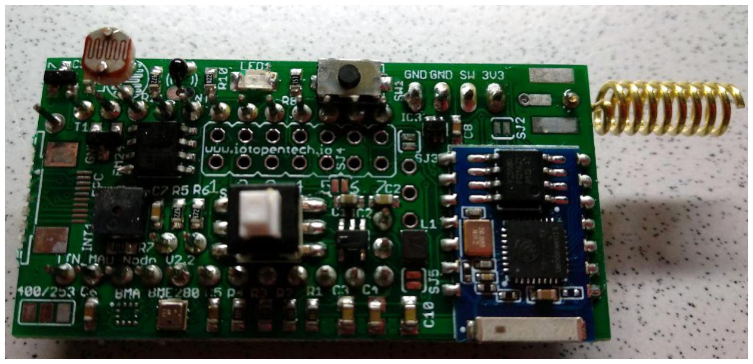
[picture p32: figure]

Vamos a crear una aplicación nueva y, dentro de ella, un

dispositivo que se una a la red por ABP.

La consola de The Things Network

Crear una aplicación

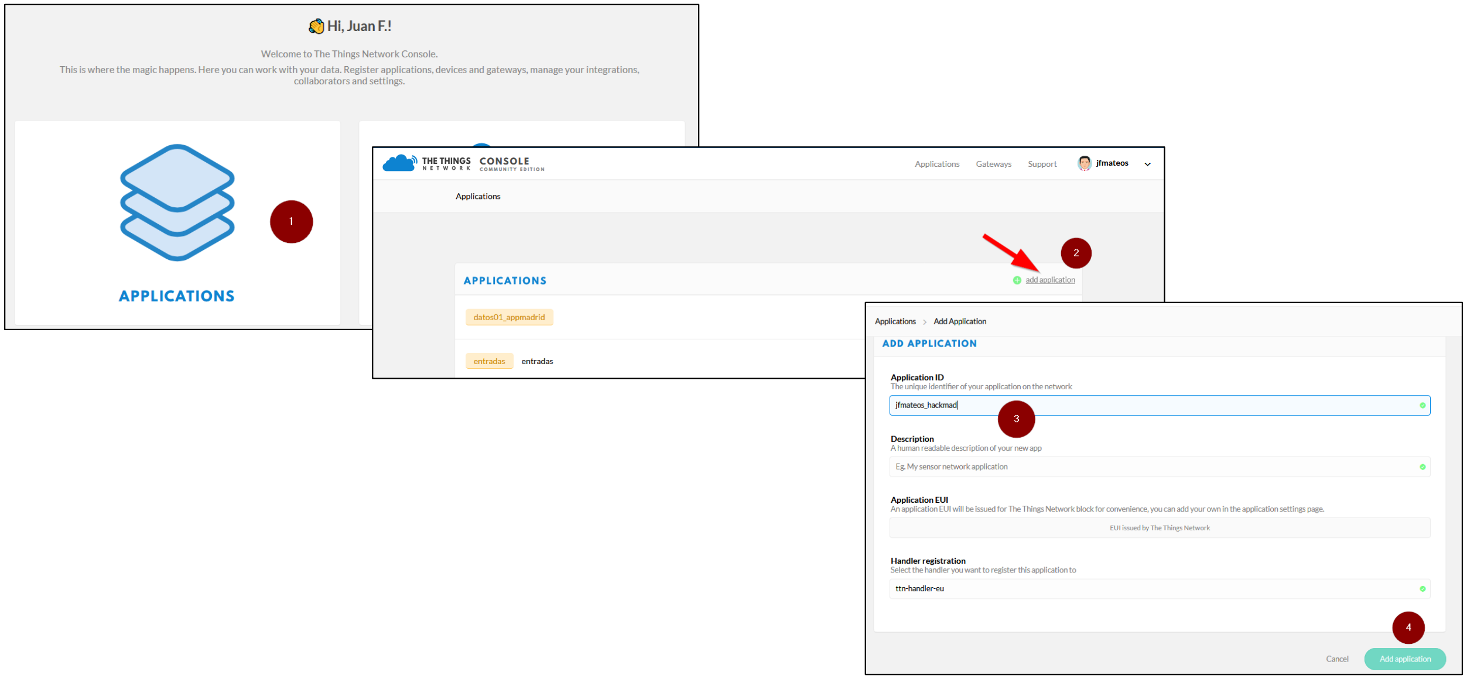
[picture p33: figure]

Añadir un dispositivo

Configurar el dispositivo para activarse por ABP

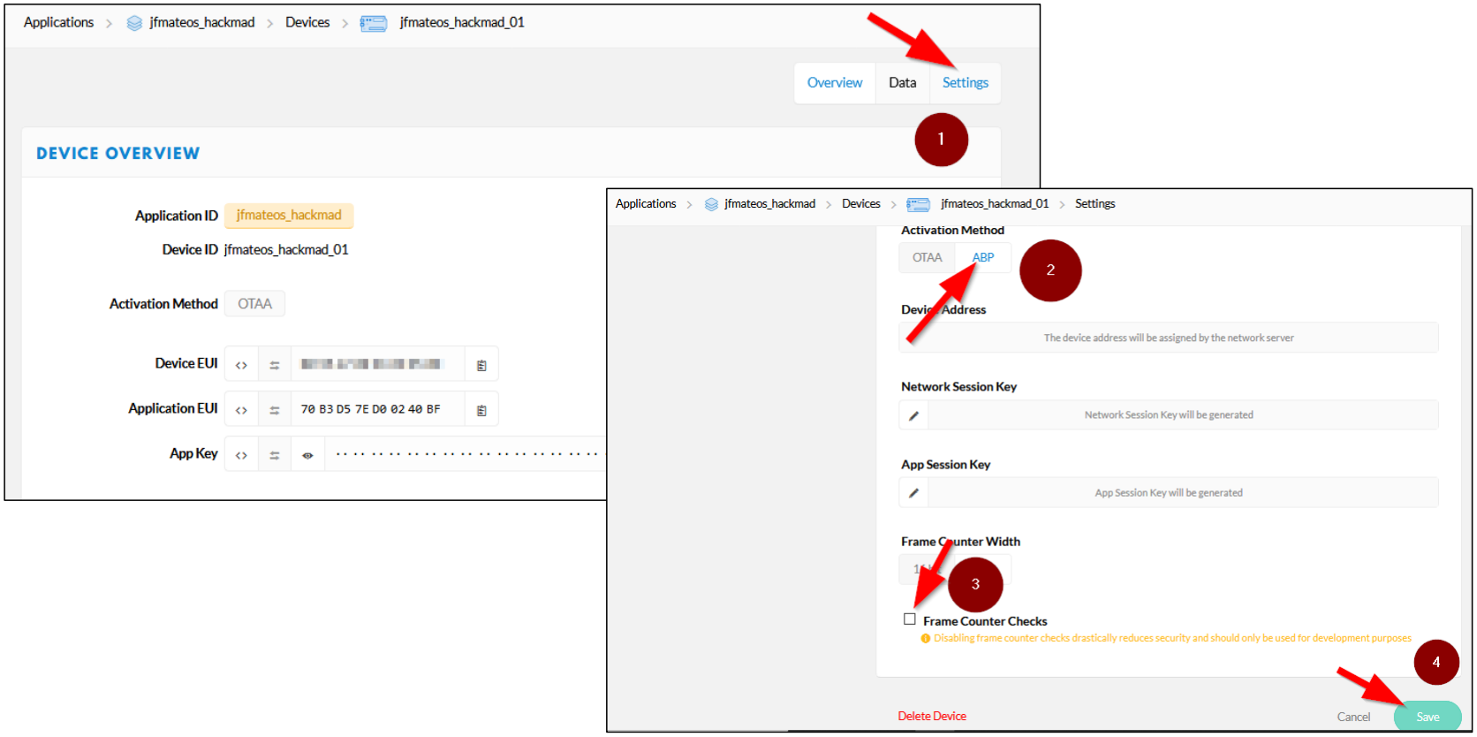
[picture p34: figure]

Activar el formato de carga de pago Cayenne LPP

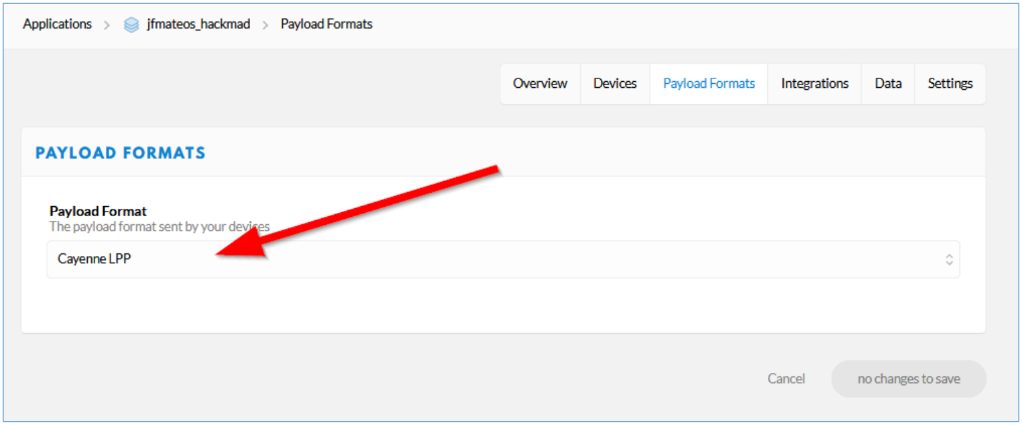
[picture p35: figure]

Vamos a crear un programa que envíe un frame con la

tensión de la batería cada 30 segundos.

Programa en Arduino para el nodo T TN MAD v2.2

Librerías de Arduino

Instalar las siguientes librerías en el IDE de Arduino:

- MCCI LoRaWAN LMIC Library by IBM, Matthis Kooijman, Terry Moore, ChaeHee Won, Frank Rose. Versión 2.3.2.
- Low-Power by Rocket Scream Electronics. Versión 1.6.0.
- CayenneLPP by Electronics Cats. Versión 1.0.1

Configurar la librería MCCI LoRaWAN LMIC Library

Para reducir al
máximo los
requisitos de
memoria de la
librería vamos a
eliminar las
funcionalidades que
no necesitamos
modificando el
siguiente archivo:

MCCI_LoRaWAN_L
MIC_library\project_
config\lmic_project_
config.h

// project-specific definitions

#define CFG_eu868 1

//#define CFG_us915 1

//#define CFG_au921 1//#define CFG_as923 1

// #define LMIC_COUNTRY_CODE LMIC_COUNTRY_CODE_JP | /* for as923-JP */

//#define CFG_in866 1

#define CFG_sx1276_radio 1

//#define LMIC_USE_INTERRUPTS

#define DISABLE_PING

#define DISABLE_BEACONS

Punto de partida

- Partimos del ejemplo
ttn-abp de la librería
MCCI LoRaWAN
LMIC Library

Indicar las credenciales del nodo

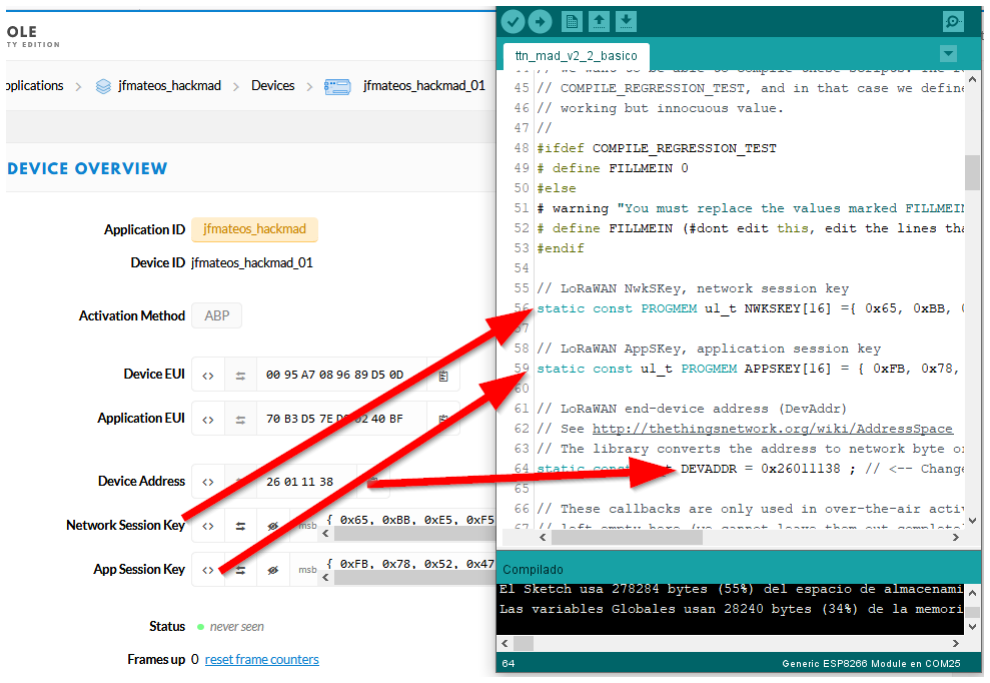
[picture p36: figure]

- Copiamos el NwkSkey
(msb), AppSkey (msb)
y DevAddr (expresar en
hexadecimal
anteponiendo 0x) de la
consola de TTN en los
lugares
correspondientes del
código.

Modificar los pines que controlan el RFM95W

- Configurar la sección
//Pin mapping como se
indica

// Pin mapping

const lmic_pinmap lmic_pins = {

.nss = 10,

.rxtx = LMIC_UNUSED_PIN,

.rst = 9,

.dio = {2, 7, LMIC_UNUSED_PIN},

};

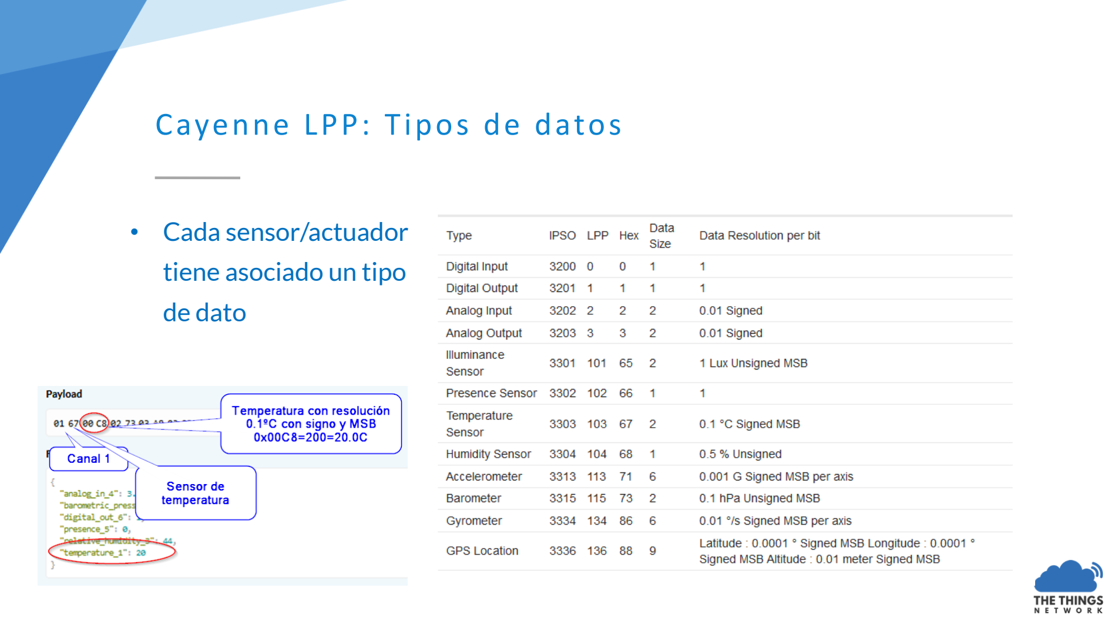
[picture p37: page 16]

Cayenne LPP: Tipos de datos

- Cada sensor/actuador
tiene asociado un tipo
de dato

Incluir las librerías lowpower y cayenne

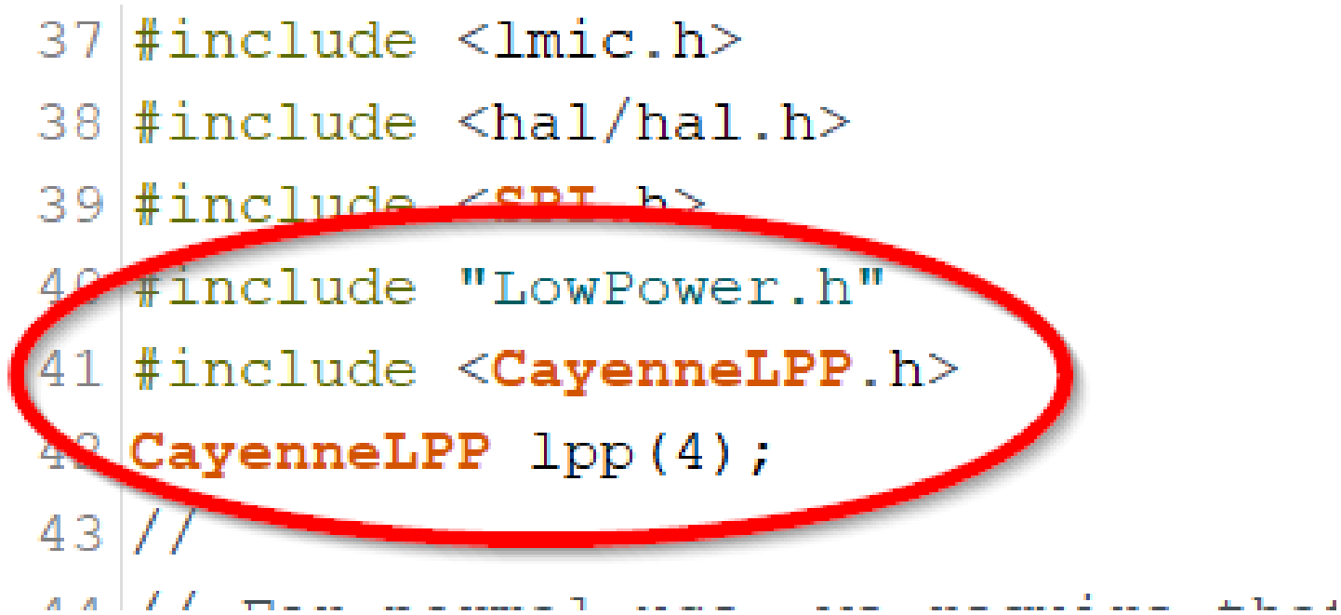
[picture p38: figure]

Insertar la función readVCC

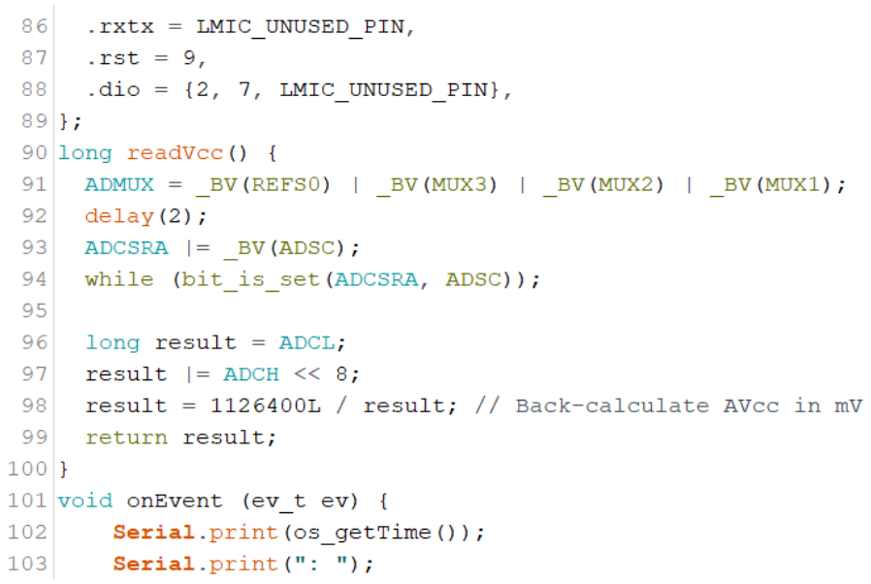
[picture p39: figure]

long readVcc() {

ADMUX = _BV(REFS0) | _BV(MUX3) | _BV(MUX2) |
_BV(MUX1);

delay(2);

ADCSRA |= _BV(ADSC);

while (bit_is_set(ADCSRA, ADSC));

long result = ADCL;

result |= ADCH << 8;

result = 1126400L / result; // Back-calculate AVcc in mV

return result;

}

Modificar el código de la función do_send

Modificar el código del estado EV_TXCOMPLETE

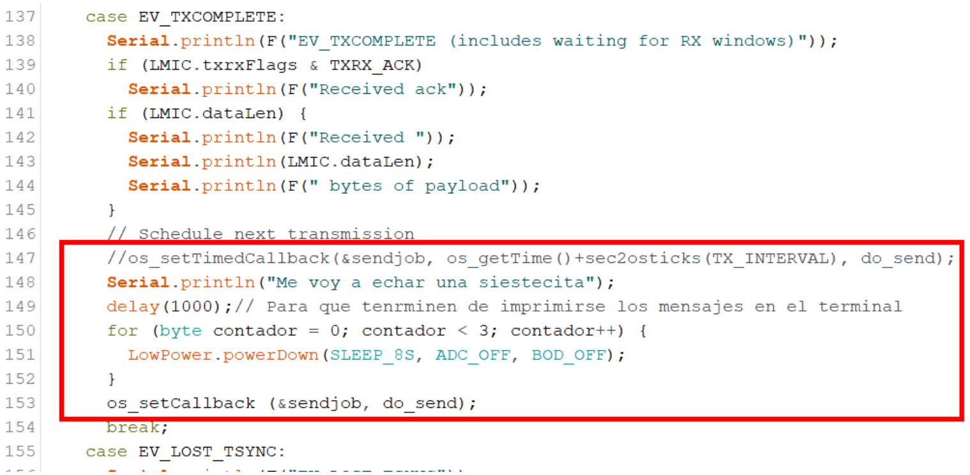
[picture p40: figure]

Configuración Básica

El nodo carece de sensores, pero puede utilizarse para

enviar paquetes o mapear coberturas con ttnmapper.

¿Configuraciones del nodo?

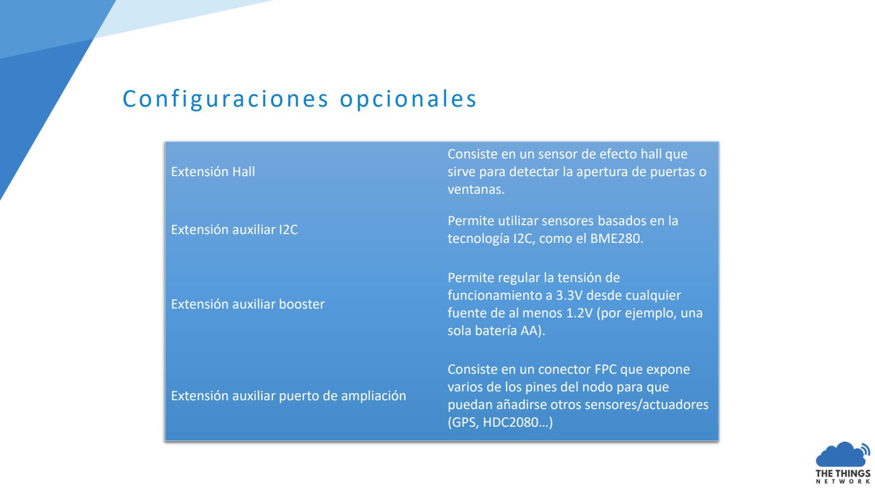
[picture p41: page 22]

Configuraciones opcionales

Extensión Hall

Consiste en un sensor de efecto hall que sirve para detectar la apertura de puertas o ventanas.

Extensión auxiliar I2C | Permite utilizar sensores basados en la tecnología I2C, como el BME280.

Extensión auxiliar booster

Permite regular la tensión de funcionamiento a 3.3V desde cualquier fuente de al menos 1.2V (por ejemplo, una sola batería AA).

Extensión auxiliar puerto de ampliación

Consiste en un conector FPC que expone varios de los pines del nodo para que puedan añadirse otros sensores/actuadores (GPS, HDC2080…)

Configuraciones opcionales

Extensión WiFi

Permite configurar el nodo a través de una página web y, potencialmente, podría utilizarse en tareas de geolocalización basadas en la ubicación de los puntos de acceso WiFi.

Extensión LDR | Consiste en un sensor de luminosidad básico.
Extensión NTC | Consiste en un sensor de temperatura básico.
Extensión LED | Consiste en un LED que podemos controlar desde Internet.
Extensión Buzzer | Consiste en un buzzer de frecuencia fija que podemos controlar desde Internet.

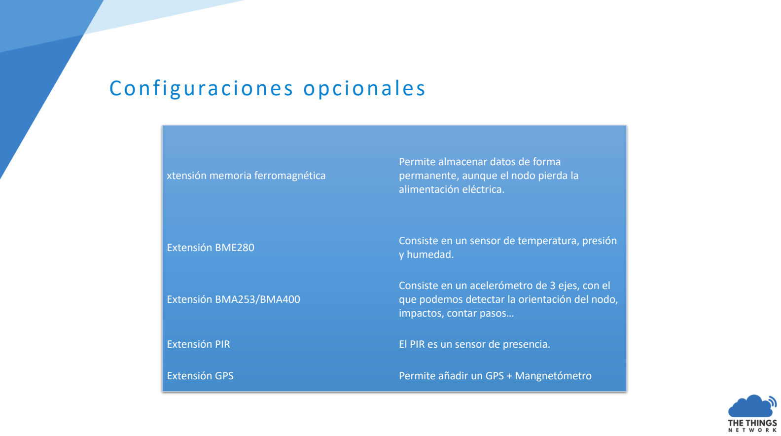
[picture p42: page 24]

Configuraciones opcionales

xtensión memoria ferromagnética

Permite almacenar datos de forma permanente, aunque el nodo pierda la alimentación eléctrica.

Extensión BME280 | Consiste en un sensor de temperatura, presión y humedad.

Extensión BMA253/BMA400

Consiste en un acelerómetro de 3 ejes, con el que podemos detectar la orientación del nodo, impactos, contar pasos…

Extensión PIR | El PIR es un sensor de presencia.
Extensión GPS | Permite añadir un GPS + Mangnetómetro

PCB

Arduino Pro mini 3v3 8MHz

RFM95W + antena helicoidal

Header 4 pines con tornillos

Pulsado On/Off

Portabaterías doble AAA

Montaje de la configuración básica

SEGURIDAD Y SOLDADURA

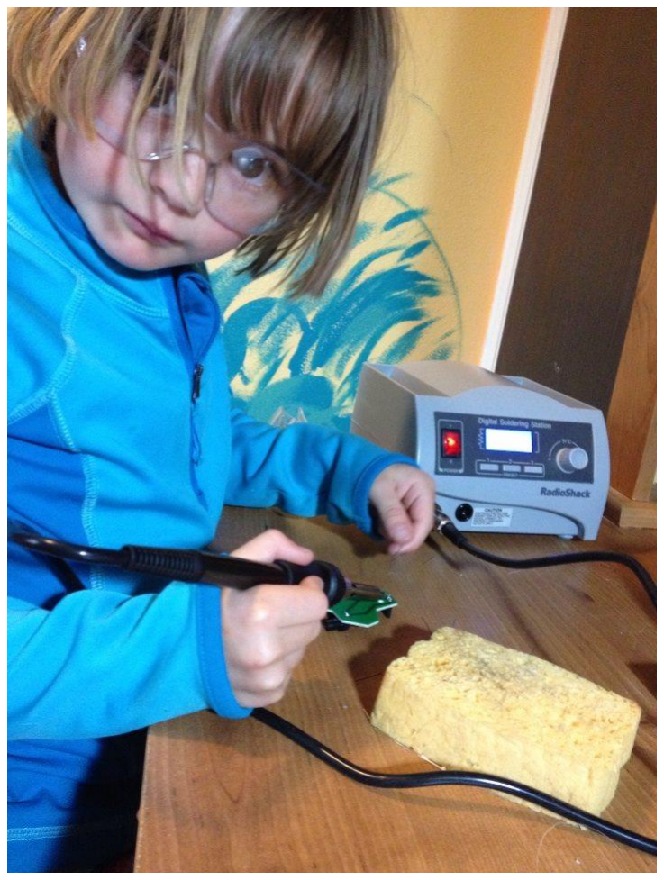
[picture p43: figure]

Riesgos
⚫ Químicos
⚫ | Plomo nunca más
⚫ | Rosin (Colofonía) ¡Ojo con asmáticos!
⚫ Térmicos
⚫ | Quemarse (poca importancia salvo que
| afecte a los ojos)
⚫ Eléctricos
⚫ | Quemar el cable del soldador → Salta el
| magnetotérmico y susto
⚫ | No usar pulseras anti-estáticas → Estorban
⚫ Mecánicos
⚫ | Punta del soldador → Pinchar al
| compañero

¿CÓMO SOLDAR?

SOLDADURA CORRECTA

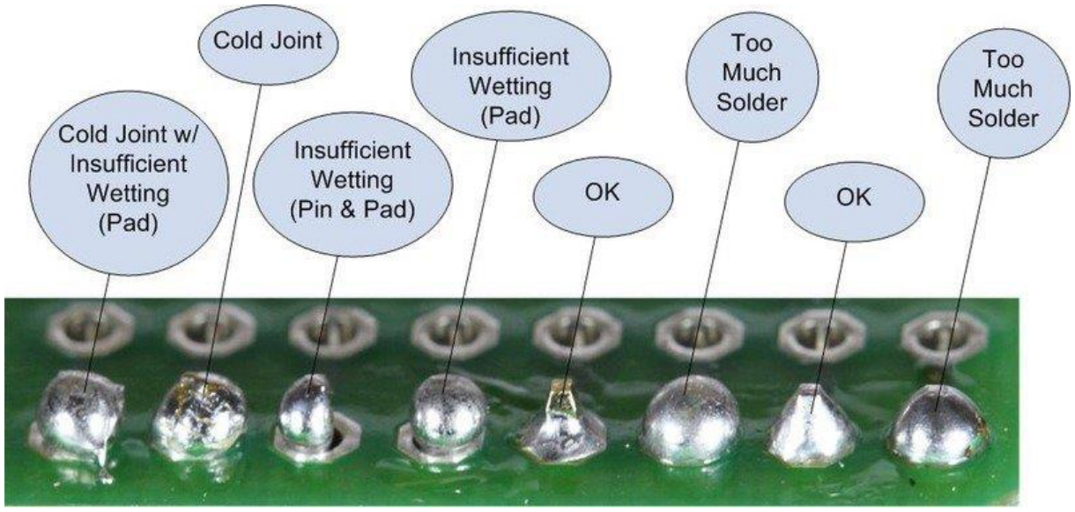
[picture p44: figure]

Componentes de la configuración básica

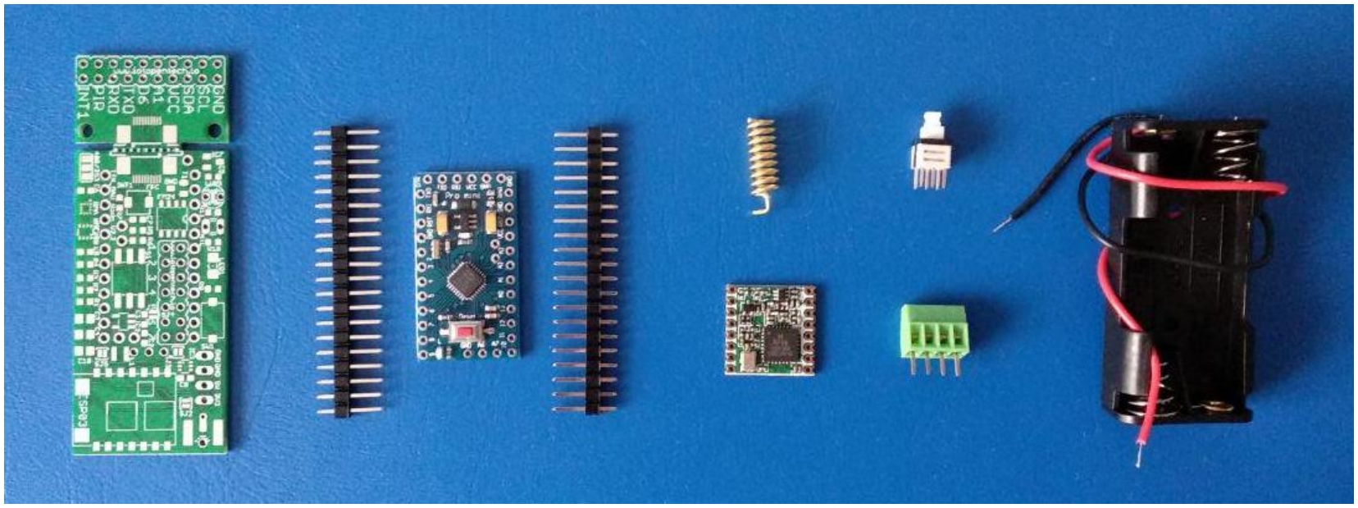
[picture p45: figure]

1. Decidir si separar o no la zona auxiliar del PCB

La zona auxiliar está pensada para facilitar el prototipado
de otras ampliaciones, como la de GPS, bien sin separar del PCB principal o bien separándola (la conexión se realiza en este caso mediante un cable plano y conectores FPC).

Si no se va a utilizar conviene separarla ahora; hacerlo después de soldar los componentes podría dañar alguna soldadura.

Para separarla, se recomienda repasar cuidadosamente la línea de mouse bites con un cutter y flexionar.

2. Solar los pines del Arduino Pro Mini

Deben soldarse:

- Las 2 tiras de pines de los lados largos del Arduino
- Los pines A4 y A5
- Los pines A6 y A7
- El pin DTR.

Obsérvese que las tiras de pines se introducen por la sección

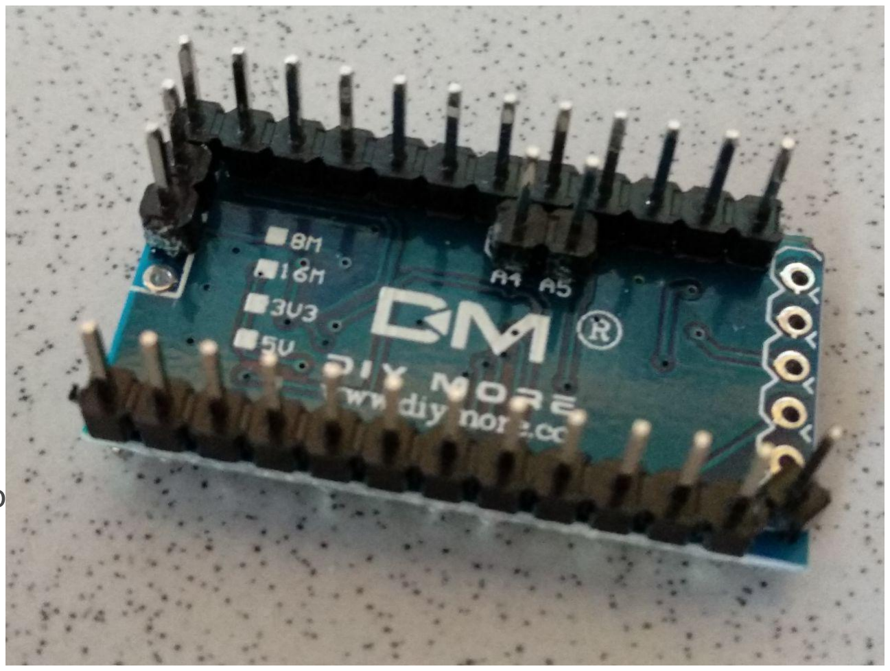
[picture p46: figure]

más corta de los pines y desde la cara posterior del Arduino Pro Mini.

Se recomienda plantear el Arduino sobre el PCB del nodo para que los pines no queden inclinados.

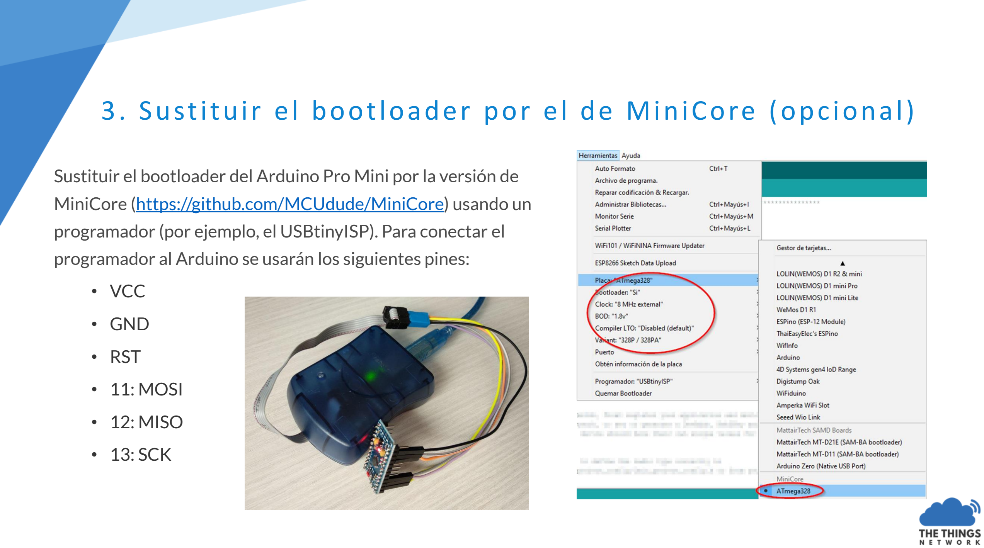
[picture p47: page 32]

3. Sustituir el bootloader por el de MiniCore (opcional)

Sustituir el bootloader del Arduino Pro Mini por la versión de MiniCore (https://github.com/MCUdude/MiniCore) usando un programador (por ejemplo, el USBtinyISP). Para conectar el programador al Arduino se usarán los siguientes pines:

- VCC
- GND
- RST
- 11: MOSI
- 12: MISO
- 13: SCK

4. Eliminar el conversor y el LED (opcional)

Eliminar el conversor de tensión y el LED de

alimentación del Arduino Pro Mini; la

eliminación de estos 2 componentes persigue

reducir el consumo al mínimo.

5. Programar el Arduino Pro Mini

Cargar el programa en el Arduino Pro Mini

usando un conversor USB → Serial

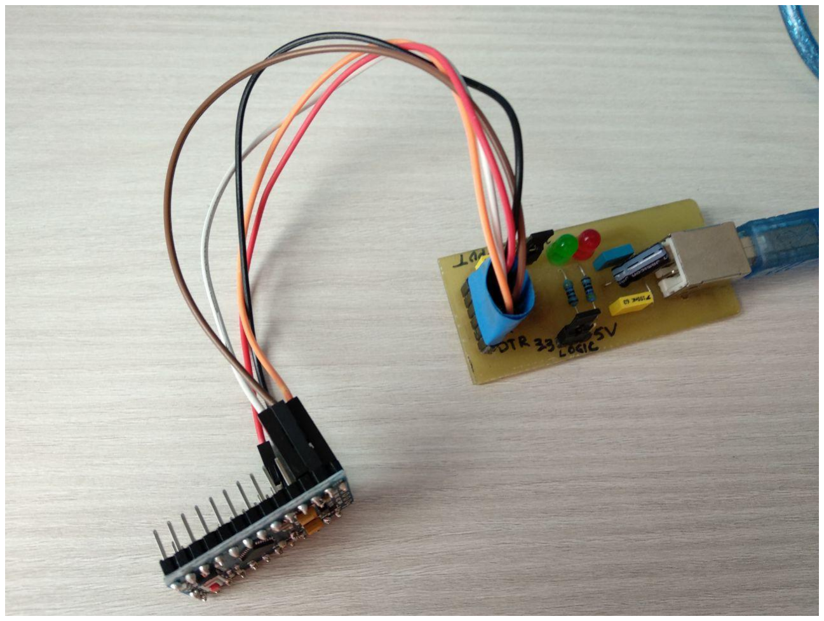
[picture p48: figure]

6. Soldar el RFM95W y la antena al PCB

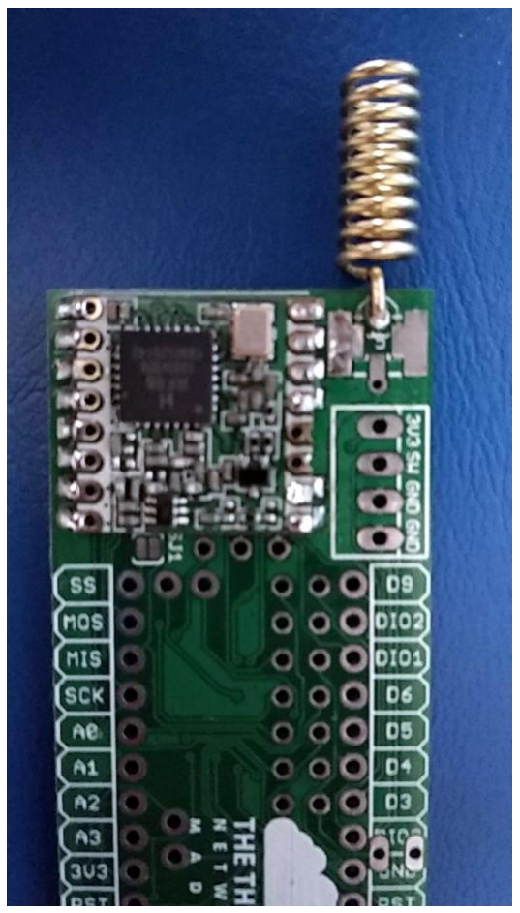
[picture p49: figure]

Prestar atención a la orientación del

RFM95W.

Se recomienda fijar "provisionalmente" uno

de los pines castelados mientras se sujeta el

módulo con un dedo para que no se mueva, y

luego soldar el resto de pines.

7. Preparación del pulsador On/Off

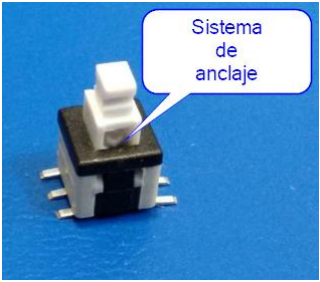
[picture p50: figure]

Doblar las patillas del pulsador On/Off y

recortarlas para que queden con una

longitud de unos 2 mm.

Obsevar que en uno de los lados del vástago

del pulsador es visible el sistema de anclaje.

8. Soldar pulsador On/Off

Soldar el pulsador dejando el sistema de

anclaje orientado hacia el borde más

próximo del PCB.

9. Soldar el Arduino y el header de 4 pines

Prestar atención a la orientación del header

de 4 pines.

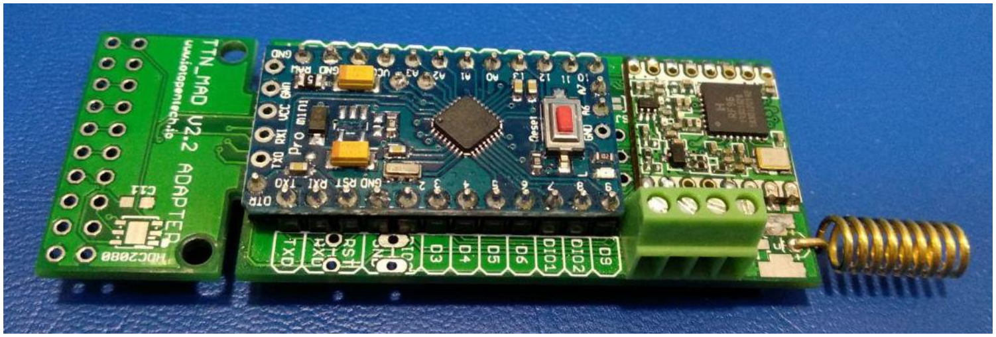
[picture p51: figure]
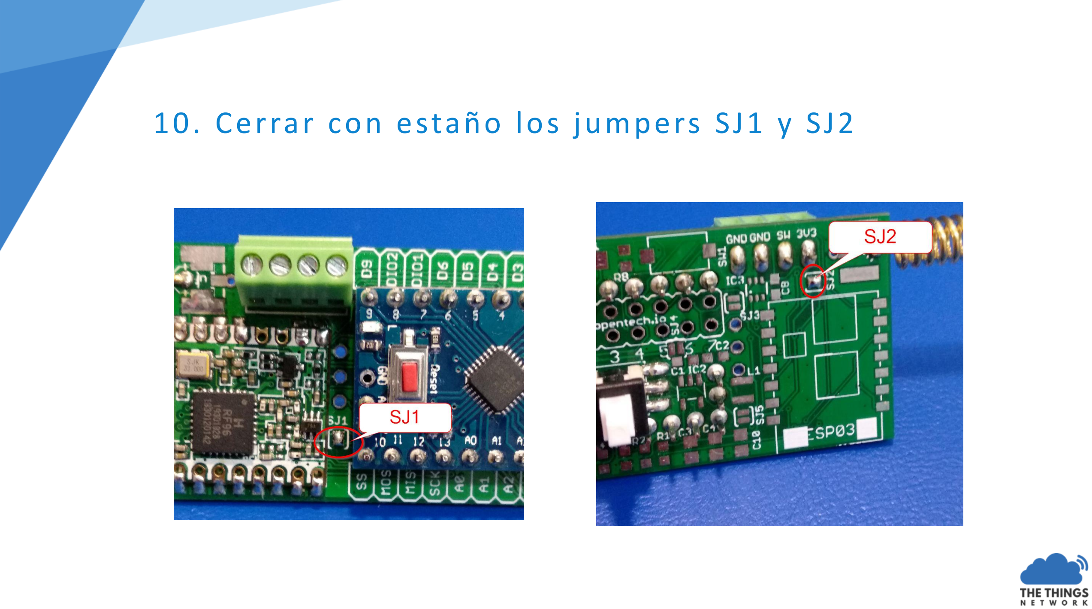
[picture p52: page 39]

10. Cerrar con estaño los jumpers SJ1 y SJ2

11. Fijar con los tornillos los cables del portabaterías

Prestar atención a la polaridad.

12. Puesta en funcionamiento

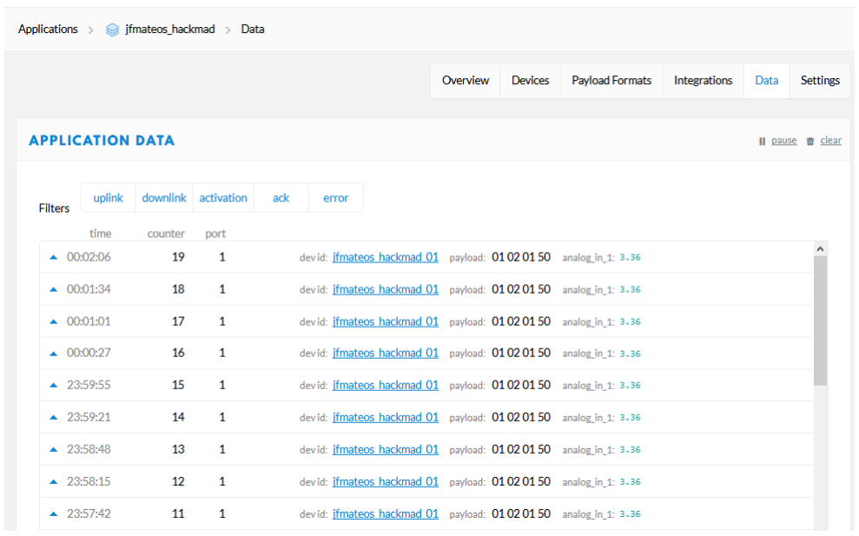
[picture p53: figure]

Insertar las baterías.

Pulsar el botón de encencido.

Los frames empezarán a aparecer en la

consola de The Things Network.

MyDevices

ttnmapper

IFTTT

NodeRED

Integraciones

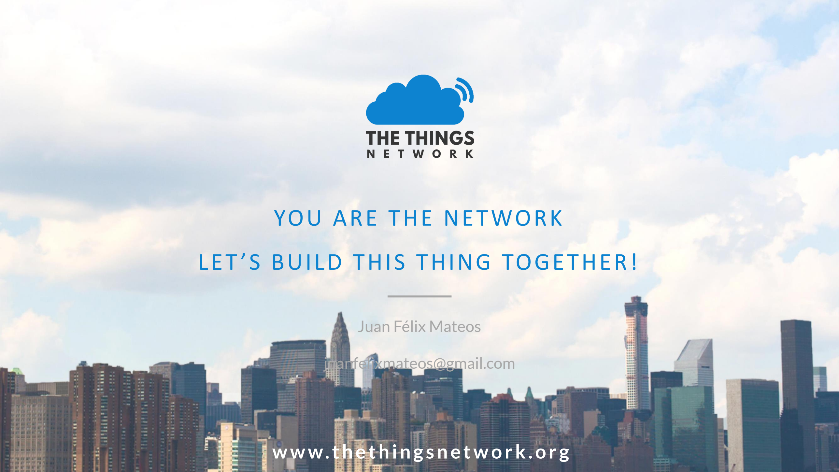
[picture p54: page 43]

YOU ARE THE NETWORK

LET ’S BUILD THIS THING TOGETHER!

Juan Félix Mateos

juanfelixmateos@gmail.com

w w w. t h e t hi n g s n e t w o r k . o r g

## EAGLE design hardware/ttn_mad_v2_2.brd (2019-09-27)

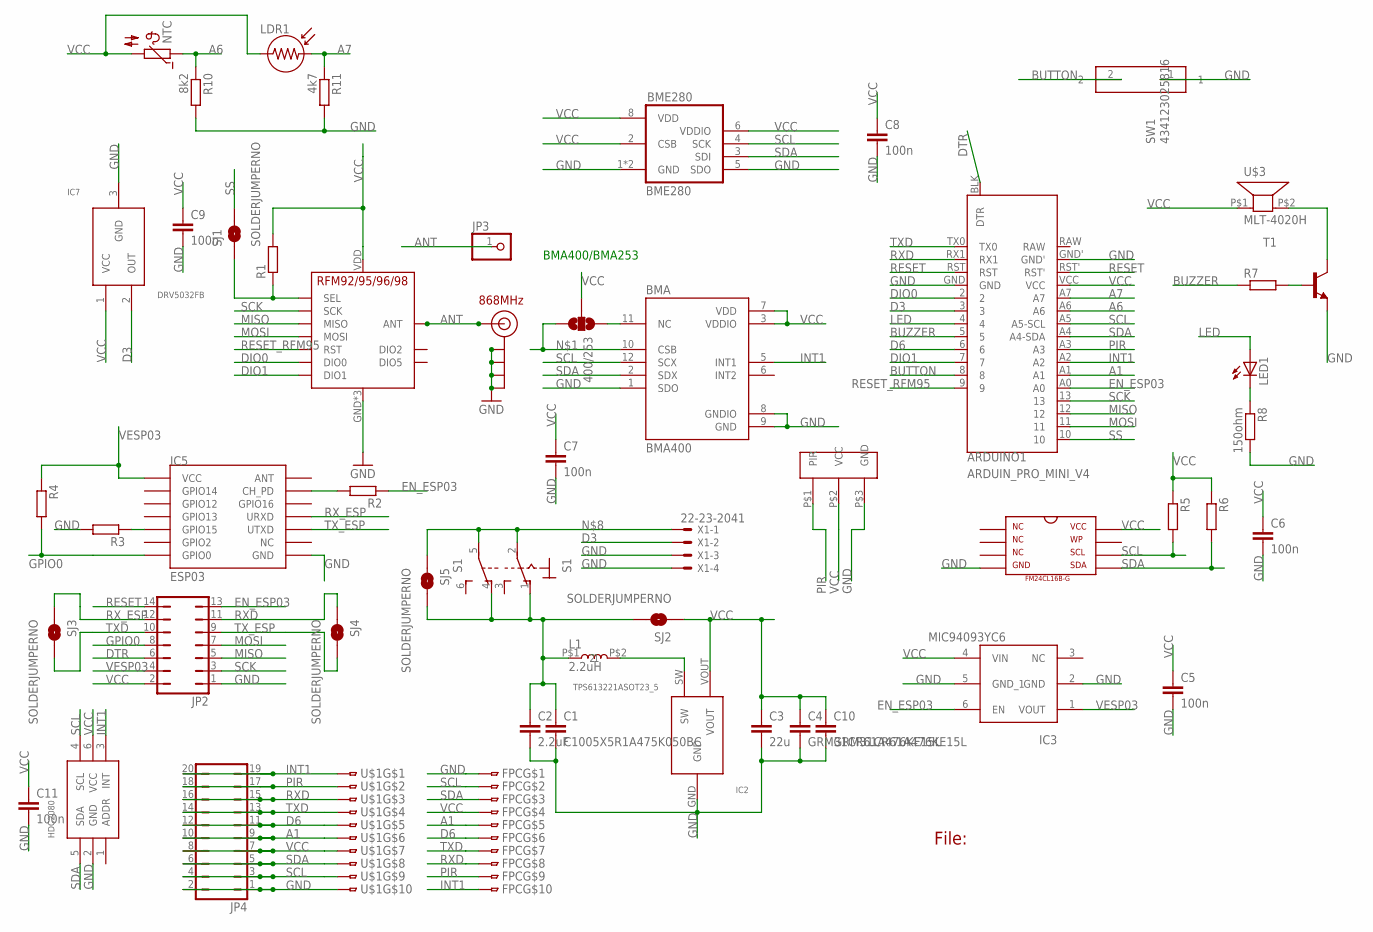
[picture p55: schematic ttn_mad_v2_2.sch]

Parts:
400/253: SOLDERJUMPER_2WAYT; SJ_2
ARDUINO1: ARDUIN_PRO_MINI_V4; ARDUINO_PRO_MINI_V4
BMA: BMA400; IC_BMA400
BME280: BME280
C1: C1005X5R1A475K050BC; C0603
C2: 2.2uF; C0603
C3: 22u; C0805
C4, C10: GRM31CR61A476KE15L; C0805
C5, C6, C7, C8, C9, C11: 100n; C0603
FM24: FM24CL16B-G
FPC: FPC_10P_0_5MM; FH12-10S-0.5SH
HDC2080: HDC2080; WSON-6
IC2: TPS613221ASOT23_5; SOT23-5L
IC3: MIC94093YC6; SC70-6
IC5: ESP03
IC7: DRV5032FB; SOT23
J$2: ANTENNATINY; SMA_UFL_PAD_TINY
JP2: JP7Q
JP3: PINHD-1X1; 1X01
JP4: JP10Q
L1: 2.2uH; SRN2512
LDR1: LDR
LED1: LEDSMT1206; 1206
NTC: NTC640; P640
R1, R2, R3, R4, R5, R6, R7: R-EU_R0603; R0603
R8: 150ohm; R0603
R10: 8k2; R0603
R11: 4k7; R0603
S1: TOGGLE_SWITCHTS_SMD; TOGGLE_SWITCH_SMD
SJ1, SJ2, SJ3, SJ4, SJ5: SOLDERJUMPERNO; SJ_2S-NO
SW1: 434123025816
T1: BC817-16-NPN-SOT23-BEC; SOT23-BEC
U$1: FPC_10P_0_5MM; FH12-10S-0.5SH
U$3: MLT-4020H
U$5: RFM95
U$6: PIR
X1: 22-23-2041

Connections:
A1: ARDUINO1.A1, FPC.5, JP4.9, JP4.10, U$1.6
A6: ARDUINO1.A6, NTC.1, R10.1
A7: ARDUINO1.A7, LDR1.2, R11.1
ANT: J$2.ANT1 (SIGNAL), J$2.ANT2 (SIGNAL), J$2.ANT3 (SIGNAL), JP3.1, U$5.ANT
BUTTON: ARDUINO1.8, SW1.2
BUZZER: ARDUINO1.5, R7.1
D3: ARDUINO1.3, IC7.2 (OUT), X1.2
D6: ARDUINO1.6, FPC.6, JP4.11, JP4.12, U$1.5
DIO0: ARDUINO1.2, U$5.DIO0
DIO1: ARDUINO1.7, U$5.DIO1
DTR: ARDUINO1.BLK (DTR), JP2.6
EN_ESP03: ARDUINO1.A0, IC3.6 (EN), JP2.13, R2.1
GND: ARDUINO1.GND, ARDUINO1.GND', BMA.1 (SDO), BMA.8 (GNDIO), BMA.9 (GND), BME280.1 (GND), BME280.5 (SDO), BME280.7 (GND), C1.2, C2.2, C3.2, C4.2, C5.2, C6.2, C7.2, C8.2, C9.2, C10.2, C11.2, FM24.4, FPC.1, HDC2080.2 (GND), IC2.GND, IC3.2 (GND), IC3.5 (GND_1), IC5.GND, IC7.3 (GND), J$2.GND1 (GND), J$2.GND2 (GND), J$2.GND3 (GND), J$2.GND4 (GND), JP2.1, JP4.1, JP4.2, R3.2, R8.2, R10.2, R11.2, SW1.1, T1.E, U$1.10, U$5.GND, U$5.GND1 (GND), U$5.GND2 (GND), U$6.P$3 (GND), X1.3, X1.4
GPIO0: IC5.GPIO0, JP2.8, R4.2
INT1: ARDUINO1.A2, BMA.5 (INT1), FPC.10, HDC2080.3 (INT), JP4.19, JP4.20, U$1.1
LED: ARDUINO1.4, LED1.A
MISO: ARDUINO1.12, JP2.5, U$5.MISO
MOSI: ARDUINO1.11, JP2.7, U$5.MOSI
unnamed: 400/253.3, BMA.10 (CSB)
unnamed: R1.1, SJ1.1, U$5.NSS (SEL)
unnamed: IC2.SW, L1.P$2 (2)
unnamed: IC5.GPIO15, R3.1
unnamed: T1.C, U$3.P$2 (2)
unnamed: 400/253.1, BMA.11 (NC)
unnamed: R7.2, T1.B
unnamed: S1.2, S1.5, SJ5.1, X1.1
unnamed: LED1.C, R8.1
unnamed: IC5.CH_PD, R2.2
PIR: ARDUINO1.A3, FPC.9, JP4.17, JP4.18, U$1.2, U$6.P$1 (PIR)
RESET: ARDUINO1.RST, ARDUINO1.RST', JP2.14
RESET_RFM95: ARDUINO1.9, U$5.RST
RXD: ARDUINO1.RX1, FPC.8, JP2.11, JP4.15, JP4.16, SJ4.1, U$1.3
RX_ESP: IC5.URXD, JP2.12, SJ3.1
SCK: ARDUINO1.13, JP2.3, U$5.SCK
SCL: ARDUINO1.A5 (A5-SCL), BMA.12 (SCX), BME280.4 (SCK), FM24.6, FPC.2, HDC2080.4 (SCL), JP4.3, JP4.4, R5.2, U$1.9
SDA: ARDUINO1.A4 (A4-SDA), BMA.2 (SDX), BME280.3 (SDI), FM24.5, FPC.3, HDC2080.5 (SDA), JP4.5, JP4.6, R6.2, U$1.8
SS: ARDUINO1.10, SJ1.2
TXD: ARDUINO1.TX0, FPC.7, JP2.10, JP4.13, JP4.14, SJ3.2, U$1.4
TX_ESP: IC5.UTXD, JP2.9, SJ4.2
VCC: 400/253.2, ARDUINO1.VCC, BMA.3 (VDDIO), BMA.7 (VDD), BME280.2 (CSB), BME280.6 (VDDIO), BME280.8 (VDD), C3.1, C4.1, C5.1, C6.1, C7.1, C8.1, C9.1, C10.1, C11.1, FM24.8, FPC.4, HDC2080.6 (VCC), IC2.VOUT, IC3.4 (VIN), IC7.1 (VCC), JP2.2, JP4.7, JP4.8, LDR1.1, NTC.2, R1.2, R5.1, R6.1, SJ2.1, U$1.7, U$3.P$1 (1), U$5.VDD (VCC), U$6.P$2 (VCC)
VCC_BAT: C1.1, C2.1, L1.P$1 (1), S1.1 (O), S1.4 (O), SJ2.2, SJ5.2
VESP03: IC3.1 (VOUT), IC5.VCC, JP2.4, R4.1

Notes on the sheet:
File:
868MHz
BMA400/BMA253

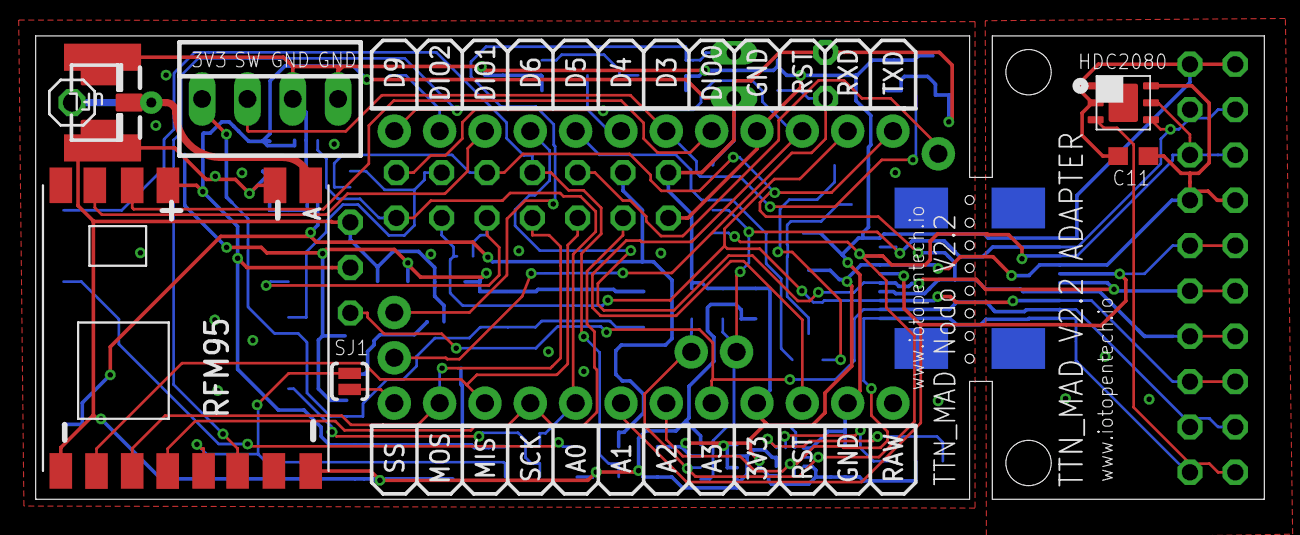
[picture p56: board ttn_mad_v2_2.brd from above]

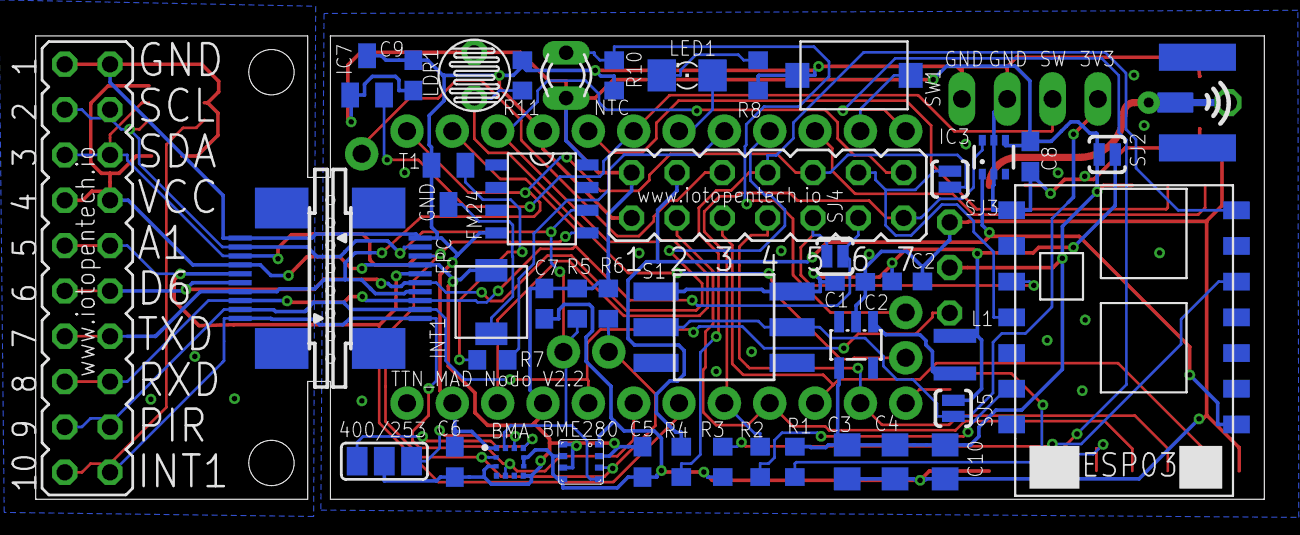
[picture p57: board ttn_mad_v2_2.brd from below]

Board: 2 copper layers, 68.8 x 26.0 mm, 53 parts (45 on the bottom side), 42 nets.

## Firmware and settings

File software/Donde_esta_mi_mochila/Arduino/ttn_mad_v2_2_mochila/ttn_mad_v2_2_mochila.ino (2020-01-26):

/*
   El nodo enviará un heartbeat cada 15' con el estado de la batería
   Si el usuario pulsa el botón 3 veces en menos de 2'', 
   dejando una separación de más de 500ms entre pulsación y pulsación, 
   se activará el modo tracking
   Con otra triple pulsación se desactivará
   Utilizo 2 ciclos de sueño alternos, uno de 500ms y otro de 8s para poder detectar
   si la triple pulsación en caso de sueño es rápida
   El modo tracking también se puede activar/desactivar remotamente con un downlink (con ACK)
   En el modo tracking el nodo enviará cada 5':
    El estado de la batería
    Las 2 MAC de AP WiFi con mejor RSSI disfrazadas como datos de luminosidad en cayenne lpp
    La posición GPS si consigue hacer FIX (intentará hacer FIX durante un máximo de 2')
*/
#define  BOTON_SOS  3
#define  BOTON_CONF 8
#define  LED        4
#define  EN_ESP03   A0
#define  EN_GPS     A3
#define  BATT       A1

#define  CICLOS_HEARTBEAT 105 //aprox 15'
#define  CICLOS_TRACKING 35 //aprox 5'
int ciclo = 0;

#include <lmic.h>
#include <hal/hal.h>

#include <SPI.h>
#include <EEPROM.h>
#include "LowPower.h"

#include <CayenneLPP.h>
CayenneLPP lpp(45);//Sólo voy a pasar la tensión [4], la entrada del botón[3], el GPS [14] y las MAC[2x12]

#include <NMEAGPS.h>
#define gpsPort Serial
NMEAGPS  gps; // This parses the GPS characters
gps_fix  fix; // This holds on to the latest values
float latitud, longitud, altitud;

unsigned long arranqueCrono;
volatile unsigned long cronoPulsacionAnterior = 0;
volatile unsigned long cicloPulsacionAnterior = 0;
volatile byte pulsacionesConsecutivas = 0;
volatile bool pulsacionRecienIncrementada = false;
volatile unsigned long pulsaciones = 0;
volatile bool envioEnCurso = false;
bool modoTracking = false;
bool GPSarrancado = false;
bool ESP03arrancado = false;
bool esperarUnPoco = false;

bool otaa_abp;


unsigned long DEVADDR = 0;
byte NWKSKEY[16] ;
byte APPSKEY[16];

void os_getDevEui (u1_t* buf) {
  for (int i = 0; i < 8; i++) {
    buf[7 - i] = NWKSKEY[i];
  }
}
void os_getArtEui (u1_t* buf) {
  for (int i = 0; i < 8; i++) {
    buf[7 - i] = NWKSKEY[8 + i];
  }
}
void os_getDevKey (u1_t* buf) {
  for (int i = 0; i < 16; i++) {
    buf[i] = APPSKEY[i];
  }
}

static osjob_t sendjob;

// Pin mapping
const lmic_pinmap lmic_pins = {
  .nss = 10,
  .rxtx = LMIC_UNUSED_PIN,
  .rst = 9,
  .dio = {2, 7, LMIC_UNUSED_PIN},
};

void onEvent (ev_t ev) {
  Serial.print(os_getTime());
  Serial.print(": ");
  switch (ev) {
    /*
      case EV_SCAN_TIMEOUT:
      Serial.println(F("EV_SCAN_TIMEOUT"));
      break;
      case EV_BEACON_FOUND:
      Serial.println(F("EV_BEACON_FOUND"));
      break;
      case EV_BEACON_MISSED:
      Serial.println(F("EV_BEACON_MISSED"));
      break;
      case EV_BEACON_TRACKED:
      Serial.println(F("EV_BEACON_TRACKED"));
      break;

      case EV_JOINING:
      Serial.println(F("EV_JOINING"));
      break;
    */
    case EV_JOINED:
      Serial.println(F("EV_JOINED"));
      {
        u4_t netid = 0;
        devaddr_t devaddr = 0;
        u1_t nwkKey[16];
        u1_t artKey[16];
        LMIC_getSessionKeys(&netid, &devaddr, nwkKey, artKey);
        /*
          Serial.print("netid: ");
          Serial.println(netid, DEC);
          Serial.print("devaddr: ");
          Serial.println(devaddr, HEX);
          Serial.print("artKey: ");
          for (int i = 0; i < sizeof(artKey); ++i) {
          Serial.print(artKey[i], HEX);
          }
          Serial.println("");
          Serial.print("nwkKey: ");
          for (int i = 0; i < sizeof(nwkKey); ++i) {
          Serial.print(nwkKey[i], HEX);
          }
          Serial.println("");
        */
      }
      // Disable link check validation (automatically enabled
      // during join, but because slow data rates change max TX
      // size, we don't use it in this example.
      LMIC_setLinkCheckMode(0);
      break;
    /*
      || This event is defined but not used in the code. No
      || point in wasting codespace on it.
      ||
      || case EV_RFU1:
      ||     Serial.println(F("EV_RFU1"));
      ||     break;
    */
    /*
      case EV_JOIN_FAILED:
      Serial.println(F("EV_JOIN_FAILED"));
      break;
      case EV_REJOIN_FAILED:
      Serial.println(F("EV_REJOIN_FAILED"));
      break;
    */
    case EV_TXCOMPLETE:
      envioEnCurso = false;
      Serial.println(F("EV_TXCOMPLETE (includes waiting for RX windows)"));

      if (LMIC.txrxFlags & TXRX_ACK)
        Serial.println(F("Received ack"));
      if (LMIC.dataLen) {
        Serial.println(F("Downlink recibido"));
        //El downlink tendrá el formato canal (02), tipo de valor (00=digital), valor (0 o 100), FF

        if (LMIC.frame[LMIC.dataBeg + 2] == 100) {
          modoTracking = true;
          ciclo = CICLOS_TRACKING;
          //digitalWrite(LED, HIGH);
        } else {
          modoTracking = false;
          //digitalWrite(LED, LOW);
        }
        esperarUnPoco = true;
        arranqueCrono = millis();
      }

      // Schedule next transmission
      //os_setTimedCallback(&sendjob, os_getTime() + sec2osticks(TX_INTERVAL), do_send);

      break;
    /*
      case EV_LOST_TSYNC:
      Serial.println(F("EV_LOST_TSYNC"));
      break;
      case EV_RESET:
      Serial.println(F("EV_RESET"));
      break;
    */
    case EV_RXCOMPLETE:
      // data received in ping slot
      Serial.println(F("EV_RXCOMPLETE"));
      break;
    /*
      case EV_LINK_DEAD:
      Serial.println(F("EV_LINK_DEAD"));
      break;
      case EV_LINK_ALIVE:
      Serial.println(F("EV_LINK_ALIVE"));
      break;
    */
    /*
      || This event is defined but not used in the code. No
      || point in wasting codespace on it.
      ||
      || case EV_SCAN_FOUND:
      ||    Serial.println(F("EV_SCAN_FOUND"));
      ||    break;
    */

    case EV_TXSTART:
      Serial.println(F("EV_TXSTART"));
      break;
    default:
      Serial.print(F("Unknown event: "));
      Serial.println((unsigned) ev);
      break;
  }
}

void do_send(osjob_t* j) {
  // Check if there is not a current TX/RX job running
  if (LMIC.opmode & OP_TXRXPEND) {
    Serial.println(F("OP_TXRXPEND, not sending"));
  } else {
    envioEnCurso = true;
    lpp.addAnalogInput(1, analogRead(BATT) * 3.3 / 1000.F);
    lpp.addDigitalOutput(2, 0);//Canal para habilitar el modo de tracking a distancia mediante un downlink

    LMIC_setTxData2(1, lpp.getBuffer(), lpp.getSize(), 0);

    Serial.println(F("Packet queued"));

  }
}
void setup() {
  Serial.begin(9600);
  pinMode(BOTON_SOS, INPUT_PULLUP);//BOTON SOS
  pinMode(BOTON_CONF, INPUT_PULLUP);//BOTON INTERNO
  pinMode(LED, OUTPUT);//LED
  //pinMode(5, OUTPUT);//BUZZER
  //pinMode(6, INPUT);//External
  pinMode(EN_ESP03, OUTPUT);//EN_ESP03
  digitalWrite(EN_ESP03, LOW);
  //pinMode(A1, INPUT);//EXTERNAL
  //pinMode(A2, INPUT);//INT1
  pinMode(EN_GPS, OUTPUT);//Enable GPS
  digitalWrite(EN_GPS, LOW);

  //Avisos de encendido

  digitalWrite(LED, HIGH);
  delay(1000);
  digitalWrite(LED, LOW);
  byte entradaSerial[16];
  // ¿Entrar en el modo de configuración?

  if ( digitalRead(BOTON_CONF) == LOW) {
    delay(500);
    if ( digitalRead(BOTON_CONF) == LOW) {
      //Entrar en modo de programación
      digitalWrite(EN_ESP03, HIGH);
      delay(1000);//Espero a que arranque el esp03

      digitalWrite(LED, HIGH);

      bool configuracionTerminada = false;
      while (!configuracionTerminada) {
        if (Serial.available()) {
          delay(100);
          Serial.readBytes(entradaSerial, 16);
          if (entradaSerial[0] == 'I' && entradaSerial[1] == 'o' && entradaSerial[2] == 'T') {
            Serial.write("1");//Entrar en modo configuración
          } else if (entradaSerial[0] == 'A' && entradaSerial[1] != 'B') {
            //No hago nada
          } else if (entradaSerial[0] == 'O' && entradaSerial[1] == 'T' && entradaSerial[2] == 'A' && entradaSerial[3] == 'A') {
            //digitalWrite(6, LOW);
            int i = 0;
            for (int j = 0 ; j < 4 ; i++, j++) {
              EEPROM.write( i, entradaSerial[j] );
            }
            while (!Serial.available()) {}
            delay(100);
            Serial.readBytes(entradaSerial, 8);
            for (int j = 0 ; j < 8 ; i++, j++) {
              EEPROM.write( i, entradaSerial[j] );
            }
            while (!Serial.available()) {}
            delay(100);
            Serial.readBytes(entradaSerial, 8);
            for (int j = 0 ; j < 8 ; i++, j++) {
              EEPROM.write( i, entradaSerial[j] );
            }
            while (!Serial.available()) {}
            delay(100);
            Serial.readBytes(entradaSerial, 16);
            for (int j = 0 ; j < 16 ; i++, j++) {
              EEPROM.write( i, entradaSerial[j] );
            }
            Serial.write("B");
            digitalWrite(LED, LOW);
            delay(5000);
            digitalWrite(EN_ESP03, LOW);
            configuracionTerminada = true;
          } else if (entradaSerial[0] == 'A' && entradaSerial[1] == 'B' && entradaSerial[2] == 'P') {
            int i = 0;
            for (int j = 0 ; j < 3 ; i++, j++) {
              EEPROM.write( i, entradaSerial[j] );
            }

            while (!Serial.available()) { }
            delay(100);
            Serial.readBytes(entradaSerial, 4);
            for (int j = 0 ; j < 4 ; i++, j++) {
              EEPROM.write( i, entradaSerial[j] );
            }

            while (!Serial.available()) {}
            delay(100);
            Serial.readBytes(entradaSerial, 16);
            for (int j = 0 ; j < 16 ; i++, j++) {
              EEPROM.write( i, entradaSerial[j] );
            }

            while (!Serial.available()) {
            }
            delay(100);
            Serial.readBytes(entradaSerial, 16);
            for (int j = 0 ; j < 16 ; i++, j++) {
              EEPROM.write( i, entradaSerial[j] );
            }
            Serial.write("B");
            digitalWrite(LED, LOW);

            delay(5000);
            digitalWrite(EN_ESP03, LOW);

            delay(100);

            configuracionTerminada = true;
          }
        }
      }

    }
  }

  //Arranque normal (sin entrar en modo configuración)
  //Leer la configuración de la eeprom
  if (EEPROM.read(0) == 'O' &&  EEPROM.read(1) == 'T' && EEPROM.read(2) == 'A' && EEPROM.read(3) == 'A' ) {
    otaa_abp = true;
    //Serial.println("OTAA");
    EEPROM.get(4, entradaSerial);
    for (int j = 7; j >= 0; j--) {
      NWKSKEY[j] = entradaSerial[j];
    }
    EEPROM.get(12, entradaSerial);
    for (int j = 7; j >= 0; j--) {
      NWKSKEY[8 + j] = entradaSerial[j];
    }
    EEPROM.get(20, entradaSerial);
    for (int j = 0; j < 16; j++) {
      APPSKEY[j] = entradaSerial[j ];
    }
  } else if (EEPROM.read(0) == 'A' &&  EEPROM.read(1) == 'B' && EEPROM.read(2) == 'P') {
    otaa_abp = false;
    //Serial.println("ABP");
    EEPROM.get(3, entradaSerial);
    for (int j = 0; j < 4; j++) {
      DEVADDR *= 256;
      DEVADDR += entradaSerial[j];
    }

    EEPROM.get(7, entradaSerial);
    //Serial.println("NWKSKEY");
    for (int j = 0; j < 16; j++) {
      NWKSKEY[j] = entradaSerial[j ];

    }
    //Serial.println("APPSKEY");
    EEPROM.get(23, entradaSerial);
    for (int j = 0; j < 16; j++) {
      APPSKEY[j] = entradaSerial[j];

    }
  } else {
    //El nodo no está configurado
    while (true) {
      digitalWrite(LED, HIGH);
      delay(200);
      digitalWrite(LED, LOW);
      delay(200);
    }
  }


  // LMIC init
  os_init();
  // Reset the MAC state. Session and pending data transfers will be discarded.
  LMIC_reset();
  LMIC_setClockError(MAX_CLOCK_ERROR * 1 / 100);
  if (otaa_abp == false) {
    LMIC_setSession (0x13, DEVADDR, NWKSKEY, APPSKEY);




#if defined(CFG_eu868)
    // Set up the channels used by the Things Network, which corresponds
    // to the defaults of most gateways. Without this, only three base
    // channels from the LoRaWAN specification are used, which certainly
    // works, so it is good for debugging, but can overload those
    // frequencies, so be sure to configure the full frequency range of
    // your network here (unless your network autoconfigures them).
    // Setting up channels should happen after LMIC_setSession, as that
    // configures the minimal channel set.
    LMIC_setupChannel(0, 868100000, DR_RANGE_MAP(DR_SF12, DR_SF7),  BAND_CENTI);      // g-band
    LMIC_setupChannel(1, 868300000, DR_RANGE_MAP(DR_SF12, DR_SF7B), BAND_CENTI);      // g-band
    LMIC_setupChannel(2, 868500000, DR_RANGE_MAP(DR_SF12, DR_SF7),  BAND_CENTI);      // g-band
    LMIC_setupChannel(3, 867100000, DR_RANGE_MAP(DR_SF12, DR_SF7),  BAND_CENTI);      // g-band
    LMIC_setupChannel(4, 867300000, DR_RANGE_MAP(DR_SF12, DR_SF7),  BAND_CENTI);      // g-band
    LMIC_setupChannel(5, 867500000, DR_RANGE_MAP(DR_SF12, DR_SF7),  BAND_CENTI);      // g-band
    LMIC_setupChannel(6, 867700000, DR_RANGE_MAP(DR_SF12, DR_SF7),  BAND_CENTI);      // g-band
    LMIC_setupChannel(7, 867900000, DR_RANGE_MAP(DR_SF12, DR_SF7),  BAND_CENTI);      // g-band
    LMIC_setupChannel(8, 868800000, DR_RANGE_MAP(DR_FSK,  DR_FSK),  BAND_MILLI);      // g2-band
    // TTN defines an additional channel at 869.525Mhz using SF9 for class B
    // devices' ping slots. LMIC does not have an easy way to define set this
    // frequency and support for class B is spotty and untested, so this
    // frequency is not configured here.
#elif defined(CFG_us915)
    // NA-US channels 0-71 are configured automatically
    // but only one group of 8 should (a subband) should be active
    // TTN recommends the second sub band, 1 in a zero based count.
    // https://github.com/TheThingsNetwork/gateway-conf/blob/master/US-global_conf.json
    LMIC_selectSubBand(1);
#endif

    // Disable link check validation
    LMIC_setLinkCheckMode(0);

    // TTN uses SF9 for its RX2 window.
    LMIC.dn2Dr = DR_SF9;

    // Set data rate and transmit power for uplink (note: txpow seems to be ignored by the library)
    LMIC_setDrTxpow(DR_SF7, 14);
  }
  // Start job


  attachInterrupt(digitalPinToInterrupt(3), toggleTracking, FALLING);

  do_send(&sendjob);

}

void toggleTracking() {
  //No puedo usar millis porque si le despierto de un sleep apenas habrá avanzado
  //Si la diferencia de tiempo respecto a la pulsación anterior es mayor que 750, reinicio el contador
  //Si es menor que 750 pero mayor que 100 (tiempo antirrebote)y no viene de estar dormido dormido avanzo el contador
  //si es menor que 25 o viene de estar dormido (ciclo!=0), me fijo en el ciclo: si es el ciclo consecutivo, avanzo el contador, si no, lo reinicio
  //En este último caso no se me ha ocurrido como implementar el antirrebote
  pulsaciones++;
  unsigned long cronoActual = millis();
  if (cronoActual - cronoPulsacionAnterior > 1000L) {
    cronoPulsacionAnterior = cronoActual;
    cicloPulsacionAnterior = ciclo;
    pulsacionesConsecutivas = 1;
  } else if (ciclo == 0) {
    if (cronoActual - cronoPulsacionAnterior > 500L) {
      cronoPulsacionAnterior = cronoActual;
      cicloPulsacionAnterior = ciclo;
      pulsacionesConsecutivas++;
    } else {
      //rebote
      return;
    }
  } else {
    pulsacionRecienIncrementada = true;
    if (ciclo == cicloPulsacionAnterior ) {
      cronoPulsacionAnterior = cronoActual;
      cicloPulsacionAnterior = ciclo;
      pulsacionesConsecutivas++;
    } else {
      cronoPulsacionAnterior = cronoActual;
      cicloPulsacionAnterior = ciclo;
      pulsacionesConsecutivas = 1;
    }
  }

  if (pulsacionesConsecutivas == 3) {
    pulsacionesConsecutivas = 0;
    if (modoTracking) {
      modoTracking = false;
      ciclo = 0;
      digitalWrite(LED, LOW);
      digitalWrite(EN_ESP03, LOW);
      digitalWrite(EN_GPS, LOW);
    } else {
      modoTracking = true;
      ciclo = CICLOS_TRACKING;
      digitalWrite(LED, HIGH);
    }
    return;
  }
}

void loop() {
  os_runloop_once();
  /*
    Serial.print(pulsaciones);
    Serial.print("-");
    Serial.print(pulsacionesConsecutivas);
    Serial.print("-");
    Serial.print(cronoPulsacionAnterior);
    Serial.print("-");
    Serial.print(cicloPulsacionAnterior);
    Serial.print("-");
    Serial.print(ciclo);
    Serial.println();
    Serial.flush();
  */
  if (esperarUnPoco) {
    //He metido esto porque parece que LMIC contesta inmediatamente
    //el ack de un downlink, en lugar de ponerlo como pigpack en el uplink siguiente
    //Por lo que no puedo dormirme inmediatamente
    //Quizás actúe así porque no tengo programado el envío de otro paquete
    if (millis() - arranqueCrono > 20 * 1000L) {
      //Serial.println("FIN DE LA ESPERA");
      esperarUnPoco = false;
    }
  } else if ((LMIC.opmode & OP_TXRXPEND) || envioEnCurso) {
    //No hago nada
  } else {
    if (modoTracking) {
      digitalWrite(LED, HIGH);
      delay(50);
      digitalWrite(LED, LOW);
      if (ciclo == CICLOS_TRACKING) {
        //Aranco el GPS y espero por un fix del GPS un máximo de 2 minutos
        //Una vez logrado el FIX o superado el plazo anterior,
        //apago el GPS, enciendo el ESP03, obtengo las MACs y envío el paquete
        arranqueCrono = millis();
        GPSarrancado = true;
        digitalWrite(EN_GPS, HIGH);
        ciclo = 0;
        //Serial.print("CICLO: ");
        //Serial.println(ciclo);
      }
      if (!GPSarrancado && !ESP03arrancado) {
        ciclo++;
        //Serial.print("CICLO: ");
        //Serial.println(ciclo);
        if (!pulsacionRecienIncrementada) {
          LowPower.powerDown(SLEEP_8S, ADC_OFF, BOD_OFF);
        } else {
          pulsacionRecienIncrementada = false;
          LowPower.powerDown(SLEEP_500MS, ADC_OFF, BOD_OFF);
          
            ciclo--;
          
          LowPower.powerDown(SLEEP_500MS, ADC_OFF, BOD_OFF);
        }
        //unsigned long crono=millis();
        //while (millis()-crono < 8*1000){}
      } else if (GPSarrancado) {
        //Serial.print("GPS: ");
        //Serial.print(millis() - arranqueCrono);
        //Serial.println("");
        delay(500);
        bool FIXconseguido = false;
        while (gps.available(Serial)) {
          fix = gps.read();
          if (fix.valid.location ) {
            latitud = (float)fix.latitude();
            longitud = (float)fix.longitude();
            altitud = (float)fix.altitude();
            FIXconseguido = true;
            break;
          }
        }
        if (FIXconseguido ||  ((millis() - arranqueCrono) > 2 * 60 * 1000L)) {
          lpp.reset();
          if (FIXconseguido) {
            lpp.addGPS(3, latitud, longitud, altitud);
          }
          GPSarrancado = false;
          ESP03arrancado = true;
          digitalWrite(EN_GPS, LOW);
          delay(1000);
          digitalWrite(EN_ESP03, HIGH);
          delay(1000);
          arranqueCrono = millis();
        }
      } else { //ESP03arrancado=true
        //Serial.print("ESP03 ARRANCADO");
        //Serial.println("");
        delay(500);
        bool MACconseguida = false;
        byte entradaSerial[7];
        while (Serial.available()) {
          delay(100);
          Serial.readBytes(entradaSerial, 7);
          //El ESP03 está constantemente enviando "IoT" y esperando 1 segundo hasta que reciba un modo (1 o 2)
          if (entradaSerial[0] == 'I' && entradaSerial[1] == 'o' && entradaSerial[2] == 'T') {

            Serial.write("2");//Entrar en modo SCAN
            Serial.println("");
            //Vacío todo el buffer de entrada Serial
            while (Serial.available() > 0) {
              char t = Serial.read();
            }
            //Serial.println("CONTESTANDO");
            //Serial.println("");

            break;
          } else if (entradaSerial[6] == '#') {
            lpp.addLuminosity(4, ((entradaSerial[0] << 8) + (entradaSerial[1])));
            lpp.addLuminosity(5, ((entradaSerial[2] << 8) + (entradaSerial[3])));
            lpp.addLuminosity(6, ((entradaSerial[4] << 8) + (entradaSerial[5])));
            //Necesito al menos 2 MAC para poder acceder a los servicios de geolocalización
            Serial.readBytes(entradaSerial, 7);
            if (entradaSerial[6] == '#') {
              lpp.addLuminosity(7, ((entradaSerial[0] << 8) + (entradaSerial[1])));
              lpp.addLuminosity(8, ((entradaSerial[2] << 8) + (entradaSerial[3])));
              lpp.addLuminosity(9, ((entradaSerial[4] << 8) + (entradaSerial[5])));
              MACconseguida = true;

              //Serial.println("");
              //Serial.println("MAC conseguida");
              //Serial.println("");
              break;
            }
          }
        }
        if (MACconseguida || (millis() - arranqueCrono > 20 * 1000L)) {
          //Salgo
          digitalWrite(EN_ESP03, LOW);
          ESP03arrancado = false;
          delay(2000);
          //Serial.println("");
          //Serial.println("ENVIANDO GPS");
          //Serial.println("");
          do_send(&sendjob);
        }
      }
    } else {
      if (ciclo == CICLOS_HEARTBEAT) {
        ciclo = 0;
        //Serial.print("CICLO: ");
        //Serial.println(ciclo);
        lpp.reset();
        //Serial.println("");
        //Serial.println("HEARTBEAT");
        //Serial.println("");
        do_send(&sendjob);
      } else {
        ciclo++;
        //Serial.print("CICLO: ");
        //Serial.println(ciclo);
        //unsigned long crono=millis();
        //while (millis()-crono < 8*1000){}
        if (!pulsacionRecienIncrementada) {
          LowPower.powerDown(SLEEP_8S, ADC_OFF, BOD_OFF);
        } else {
          pulsacionRecienIncrementada = false;

          LowPower.powerDown(SLEEP_500MS, ADC_OFF, BOD_OFF);
          
            ciclo--;
          
          LowPower.powerDown(SLEEP_500MS, ADC_OFF, BOD_OFF);
        }
      }
    }
  }

}

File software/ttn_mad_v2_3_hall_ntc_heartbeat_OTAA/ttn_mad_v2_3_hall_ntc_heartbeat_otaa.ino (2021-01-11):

/*******************************************************************************
   Copyright (c) 2015 Thomas Telkamp and Matthijs Kooijman
   Copyright (c) 2018 Terry Moore, MCCI
   Permission is hereby granted, free of charge, to anyone
   obtaining a copy of this document and accompanying files,
   to do whatever they want with them without any restriction,
   including, but not limited to, copying, modification and redistribution.
   NO WARRANTY OF ANY KIND IS PROVIDED.
   This example sends a valid LoRaWAN packet with payload "Hello,
   world!", using frequency and encryption settings matching those of
   the The Things Network.
   This uses ABP (Activation-by-personalisation), where a DevAddr and
   Session keys are preconfigured (unlike OTAA, where a DevEUI and
   application key is configured, while the DevAddr and session keys are
   assigned/generated in the over-the-air-activation procedure).
   Note: LoRaWAN per sub-band duty-cycle limitation is enforced (1% in
   g1, 0.1% in g2), but not the TTN fair usage policy (which is probably
   violated by this sketch when left running for longer)!
   To use this sketch, first register your application and device with
   the things network, to set or generate a DevAddr, NwkSKey and
   AppSKey. Each device should have their own unique values for these
   fields.
   Do not forget to define the radio type correctly in
   arduino-lmic/project_config/lmic_project_config.h or from your BOARDS.txt.
 *******************************************************************************/

// References:
// [feather] adafruit-feather-m0-radio-with-lora-module.pdf

#define NTCPin A6
#define R_PULL_DOWN 8200
#define R_25 10000
#define TEMPERATURA_NOMINAL 25
#define COEFICIENTE_BETA 3950

#include <SPI.h>
#include "LowPower.h"
#include <lmic.h>
#include <hal/hal.h>

#include <CayenneLPP.h>
CayenneLPP lpp(22);

boolean envioEnCurso = false;
boolean puertaAbierta;
boolean interrumpido = false;
byte minutosHearbeat = 60;
//
// For normal use, we require that you edit the sketch to replace FILLMEIN
// with values assigned by the TTN console. However, for regression tests,
// we want to be able to compile these scripts. The regression tests define
// COMPILE_REGRESSION_TEST, and in that case we define FILLMEIN to a non-
// working but innocuous value.
//
#ifdef COMPILE_REGRESSION_TEST
# define FILLMEIN 0
#else
# warning "You must replace the values marked FILLMEIN with real values from the TTN control panel!"
# define FILLMEIN (#dont edit this, edit the lines that use FILLMEIN)
#endif

// This EUI must be in little-endian format, so least-significant-byte
// first. When copying an EUI from ttnctl output, this means to reverse
// the bytes. For TTN issued EUIs the last bytes should be 0xD5, 0xB3,
// 0x70.
static const u1_t PROGMEM APPEUI[8]={ FILLMEIN };
void os_getArtEui (u1_t* buf) { memcpy_P(buf, APPEUI, 8);}

// This should also be in little endian format, see above.
static const u1_t PROGMEM DEVEUI[8]={ FILLMEIN };
void os_getDevEui (u1_t* buf) { memcpy_P(buf, DEVEUI, 8);}

// This key should be in big endian format (or, since it is not really a
// number but a block of memory, endianness does not really apply). In
// practice, a key taken from ttnctl can be copied as-is.
static const u1_t PROGMEM APPKEY[16] = { FILLMEIN };
void os_getDevKey (u1_t* buf) {  memcpy_P(buf, APPKEY, 16);}

//static uint8_t mydata[] = "Hello, world!";
static osjob_t sendjob;

// Schedule TX every this many seconds (might become longer due to duty
// cycle limitations).
//const unsigned TX_INTERVAL = 60;

// Pin mapping
const lmic_pinmap lmic_pins = {
  .nss = 10,
  .rxtx = LMIC_UNUSED_PIN,
  .rst = 9,
  .dio = {2, 7, LMIC_UNUSED_PIN},
};

long readVcc() {
  ADMUX = _BV(REFS0) | _BV(MUX3) | _BV(MUX2) | _BV(MUX1);
  delay(2);
  ADCSRA |= _BV(ADSC);
  while (bit_is_set(ADCSRA, ADSC));

  long result = ADCL;
  result |= ADCH << 8;
  result = 1126400L / result; // Back-calculate AVcc in mV
  return result;
}
void enviarMensaje() {
  envioEnCurso = true;
  interrumpido = true;
  os_setCallback (&sendjob, do_send);
}

void onEvent (ev_t ev) {
  Serial.print(os_getTime());
  Serial.print(": ");
  switch (ev) {
    case EV_SCAN_TIMEOUT:
      //Serial.println(F("EV_SCAN_TIMEOUT"));
      break;
    case EV_BEACON_FOUND:
      //Serial.println(F("EV_BEACON_FOUND"));
      break;
    case EV_BEACON_MISSED:
      //Serial.println(F("EV_BEACON_MISSED"));
      break;
    case EV_BEACON_TRACKED:
      //Serial.println(F("EV_BEACON_TRACKED"));
      break;
    case EV_JOINING:
      //Serial.println(F("EV_JOINING"));
      break;
    case EV_JOINED:
      //Serial.println(F("EV_JOINED"));
      break;
    /*
      || This event is defined but not used in the code. No
      || point in wasting codespace on it.
      ||
      || case EV_RFU1:
      ||     Serial.println(F("EV_RFU1"));
      ||     break;
    */
    case EV_JOIN_FAILED:
      //Serial.println(F("EV_JOIN_FAILED"));
      break;
    case EV_REJOIN_FAILED:
      //Serial.println(F("EV_REJOIN_FAILED"));
      break;
    case EV_TXCOMPLETE:
      Serial.println(F("EV_TXCOMPLETE (includes waiting for RX windows)"));
      if (LMIC.txrxFlags & TXRX_ACK)
        Serial.println(F("Received ack"));
      if (LMIC.dataLen) {
        //Serial.println(F("Received "));
        //Serial.println(LMIC.dataLen);
        //Serial.println(F(" bytes of payload"));
        //El downlink tendrá el formato canal (06), tipo de valor (00=digital), valor (0 o 100), FF
        //if (LMIC.frame[LMIC.dataBeg + 2] == 100) {
        //  digitalWrite(4, HIGH);
        //} else {
        //  digitalWrite(4, LOW);
        //}
      }
      // Schedule next transmission
      //os_setTimedCallback(&sendjob, os_getTime()+sec2osticks(TX_INTERVAL), do_send);
      envioEnCurso = false;
      break;
    case EV_LOST_TSYNC:
      //Serial.println(F("EV_LOST_TSYNC"));
      break;
    case EV_RESET:
      Serial.println(F("EV_RESET"));
      break;
    case EV_RXCOMPLETE:
      // data received in ping slot
      Serial.println(F("EV_RXCOMPLETE"));
      break;
    case EV_LINK_DEAD:
      //Serial.println(F("EV_LINK_DEAD"));
      break;
    case EV_LINK_ALIVE:
      //Serial.println(F("EV_LINK_ALIVE"));
      break;
    /*
      || This event is defined but not used in the code. No
      || point in wasting codespace on it.
      ||
      || case EV_SCAN_FOUND:
      ||    Serial.println(F("EV_SCAN_FOUND"));
      ||    break;
    */
    case EV_TXSTART:
      Serial.println(F("EV_TXSTART"));
      break;
    default:
      Serial.print(F("Unknown event: "));
      Serial.println((unsigned) ev);
      break;
  }
}
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

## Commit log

2020-01-16 Reconfiguración de directorios
2020-02-16 Ejemplos con downlink al LED

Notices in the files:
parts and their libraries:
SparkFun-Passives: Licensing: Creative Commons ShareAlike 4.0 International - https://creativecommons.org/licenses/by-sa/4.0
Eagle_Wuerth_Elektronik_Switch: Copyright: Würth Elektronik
